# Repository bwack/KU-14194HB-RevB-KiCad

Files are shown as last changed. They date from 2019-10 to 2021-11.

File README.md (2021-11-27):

# KU-14194HB-RevB-KiCad

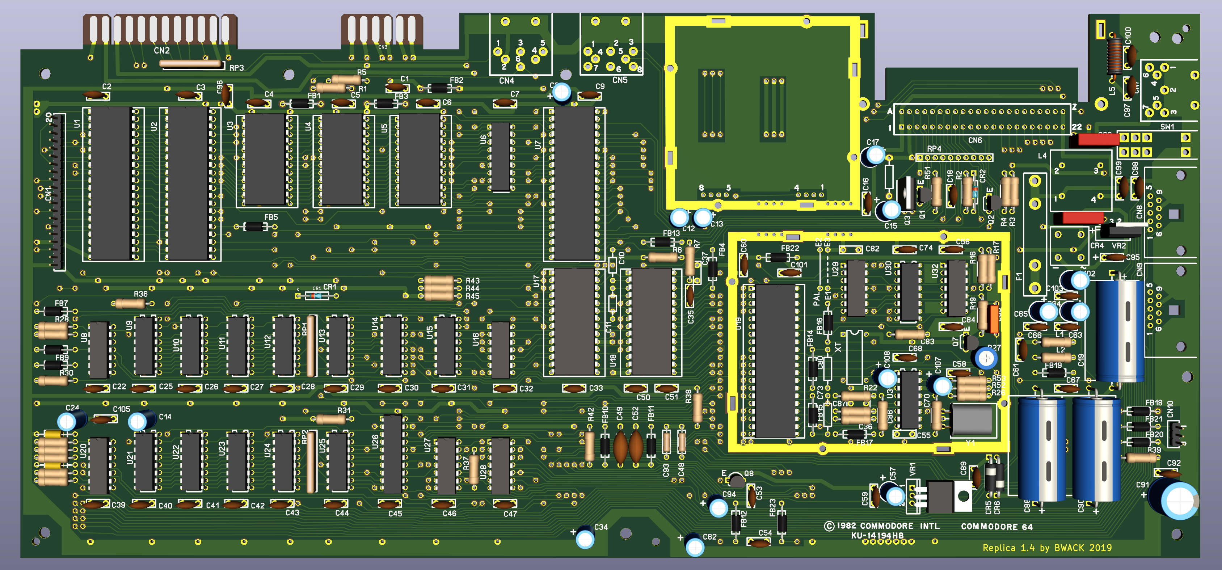
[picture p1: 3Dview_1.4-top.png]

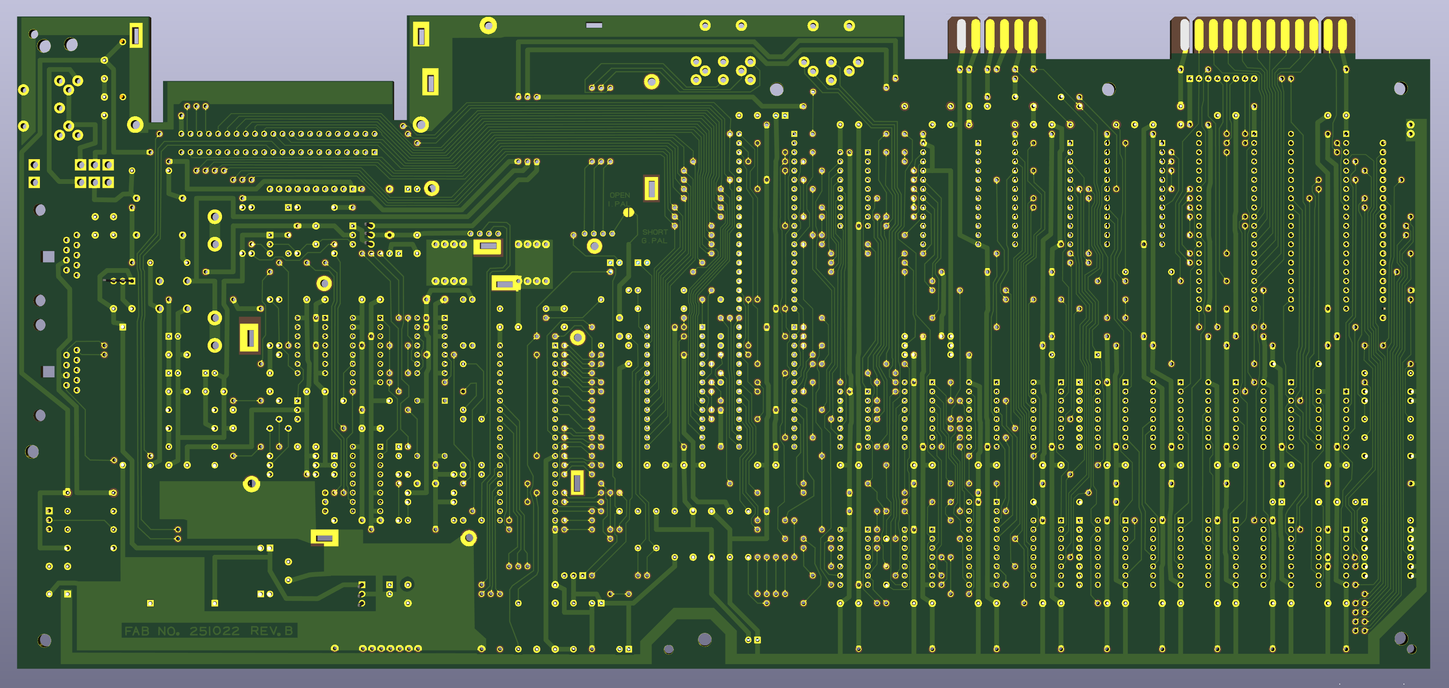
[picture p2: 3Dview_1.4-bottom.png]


The rare KU14194HB C64 Motherboard schematics and layout. Retraced in and imported from SprintLayout.

[Disclaimer](https://github.com/bwack/KU-14194HB-RevB-KiCad/blob/master/DISCLAIMER.md)

# Original bodges

This PCB is a replica. It includes the mistakes that Commodore made.

It is necessary to cut a trace above R37 on the bottom side, and add a 1K resistor from R37 and up to a via.
See the images folder to where to cut and add a resistor.

Piggyback a 100nF capacitor over CR1.

Notice how the main crystal oscillator Y1 body is grounded with a wire.

In later designs 250407 Reb B I think, 4 piggybacked diodes were introduced to protect the serial lines when hotplugging the disc drive.
I haven't added these myself, but I see the value of having those. I might add instructions here later on how to add the diodes.

# BOM

Please see the [BOM file](bom.csv).

# Interactive-BOM

[The interactive bom html page](https://htmlpreview.github.io/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) is useful for assembling the board and finding signal traces by using a web browser. Try it here. For a BOM for ordering parts see the BOM above.

# Questions

* Feel free post questions in the issues section. I will provide more information here later.

# Change log

- 2020-01-23: V1.4 PCB improvements:
  - Expansion Port: Larger round solder pads for the shield. Same error in the original.
  - Expansion Port: Connector moved to center of shield. Some traces moved.
  - Left edge: Extended the PCB by 2.2mm.
  - Left edge: Increased track width of the power rails.
  - CAN shield: added two solder pads.
  - RF modulator: added solder pad.
  - Schematics: Rev 1.4. No change.
- 2019-11-12: V1.3 Fixes: Mostly missing values.
  - C88: "1000uF 25V" -> "470uF 50uF". Commodore said 1000 but used 470.
  - R31: "180" -> "1K". A mistake in the commodore schematics.
  - R52: "?" -> "330"
  - R53: "?" -> "100"
  - C86: "?" -> "82pF",
  - C36: "0.1" -> "20pF",
  - R22: missing trace. R22 = 0 Ohm. Parallel to C87 (NC). R22 doesn't matter.
  - C101: is a Y5U. VIC2's decoupling cap. Has a higher dielectric rating. Doesn't matter.
  - C70: 15pF 5%. This is a PAL only board. In later revisions, 16pF is used for NTSC.
 - 2019-11-10 V1.2 Added missing C14 10uF 25V electrolytic capacitor
- 2019-10-15 V1.1 Layout: Fixed missing keying-slot in user port.
- 2019-10-05 V1.0 First release.

# YouTube

A playlist of all the videos:

[playlist](
https://www.youtube.com/watch?v=iNxOm7G6efA&list=PLtQOf_JULmrTGLZCElGG_T1a01JSDP0CP)

# In the wind

forum64.de: The board has some threads at forum64.de (German). May require login.
* [Bilder SHOWROOM für Repro-Boards... KU-14194HB](https://www.forum64.de/index.php?thread/97205-bilder-showroom-f%C3%BCr-repro-boards-ku-14194hb/&pageNo=1)
* [KU-14194 Bestückungs-Thread](https://www.forum64.de/index.php?thread/96336-ku-14194-best%C3%BCckungs-thread/)
* [KU-14194](https://www.forum64.de/index.php?thread/95454-ku-14194/) (long group buy thread)
* [KU-14194 (Replika) ... wer schafft es als Erste/r? Aktuelle Sachstandsberichte ...](https://www.forum64.de/index.php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)

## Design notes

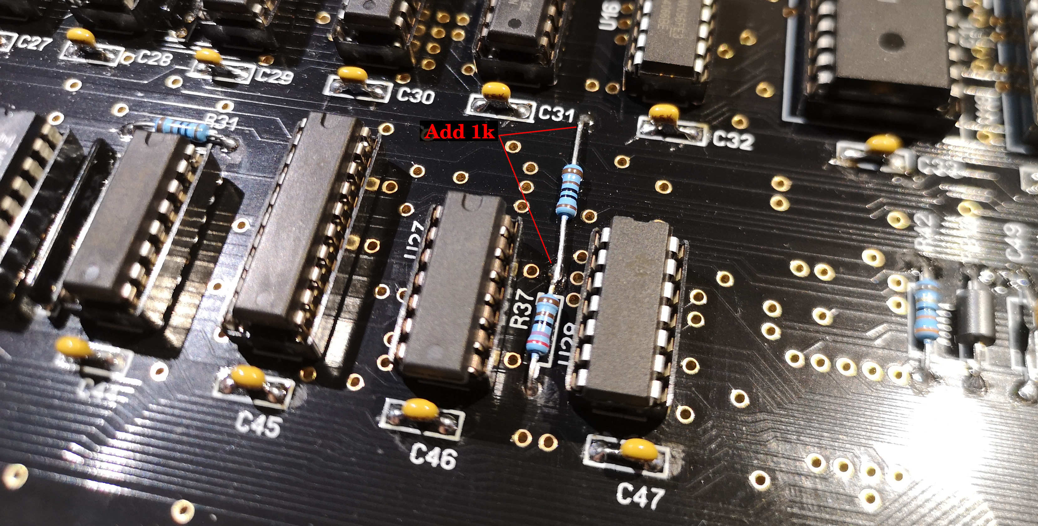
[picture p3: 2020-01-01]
images/r37_mod.jpg

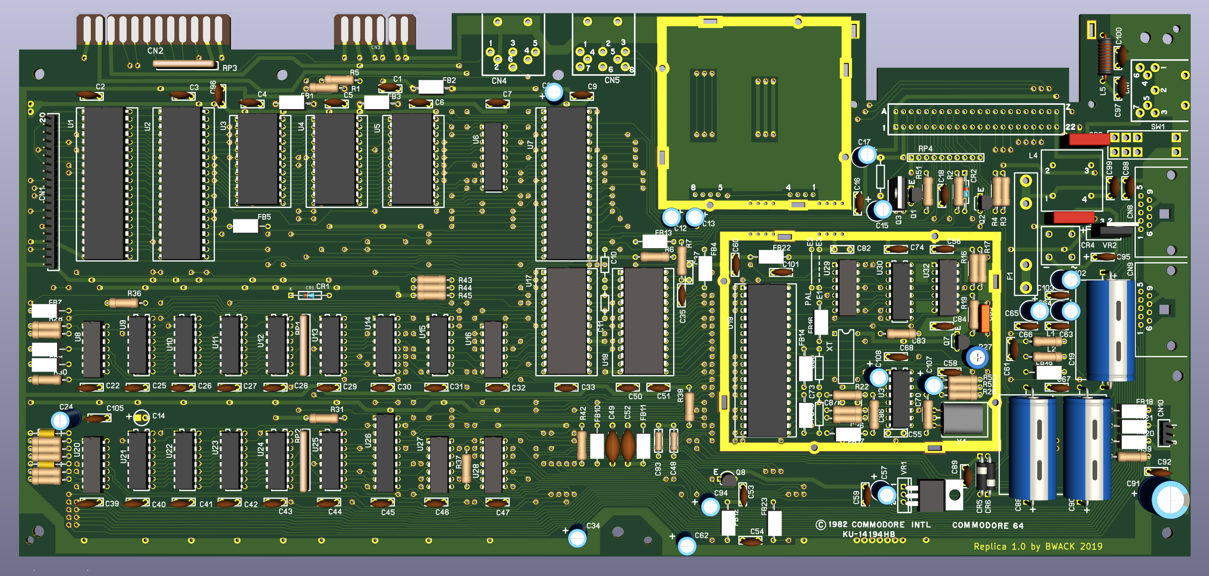
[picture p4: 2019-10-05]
3Dview_1.0_front.png

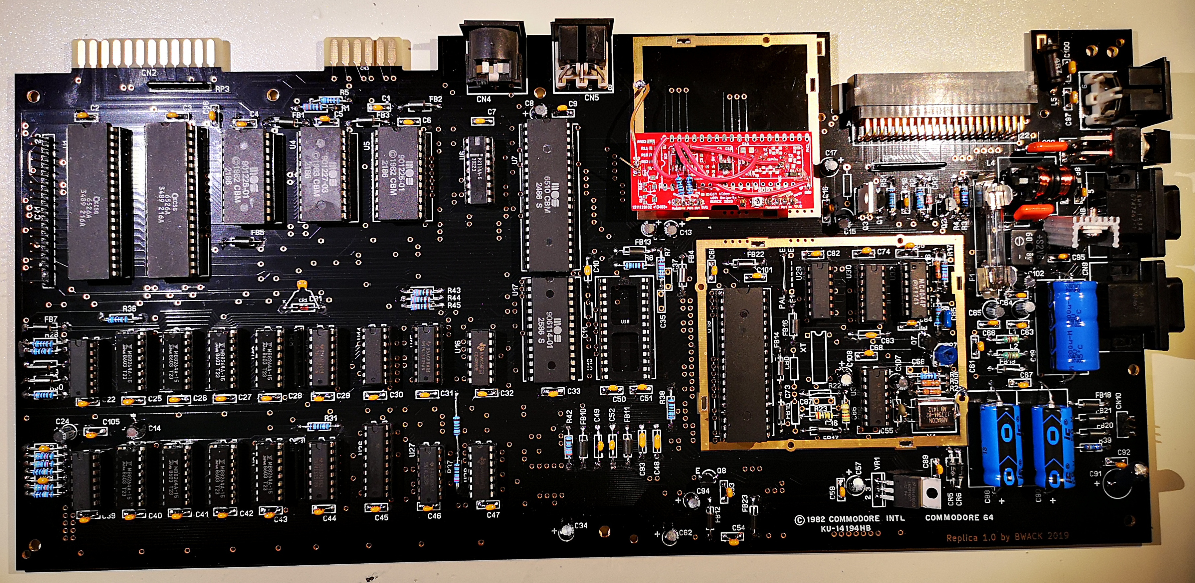
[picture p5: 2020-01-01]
images/IMG_20200101_211740_top_v1_0.jpg

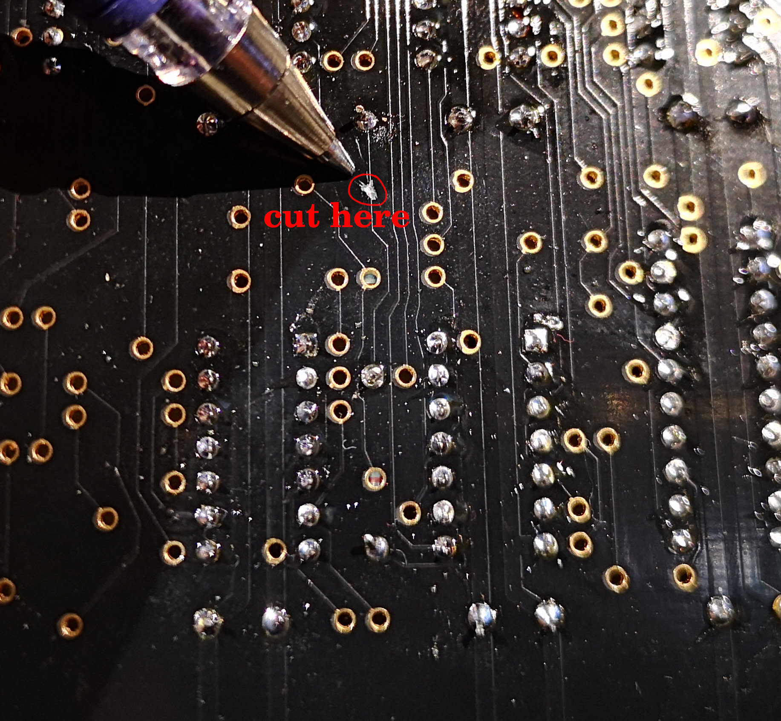
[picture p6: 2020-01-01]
images/r37_cut_trace.jpg

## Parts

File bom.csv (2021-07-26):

Qty | Reference(s) | Value | Description | Mouser P/N | Reichelt P/N | Other
56 | C1 C2 C3 C4 C5 C6 C7 C9 C16 C18 C22 C25 C26 C27 C28 C29 C30 C31 C32 C33 C39 C40 C41 C42 C43 C44 C45 C46 C47 C49 C50 C51 C52 C53 C54 C56 C58 C59 C60 C61 C63 C66 C67 C68 C74 C84 C89 C92 C95 C96 C98 C99 C101 C103 C105 and one piggybacked over CR1 | 0.1 | Cap MLCC 0.1uF 50V X7R P5.08mm Radial | 80-C322C104K5R5TA or 581-SR215C104KART | X7R-5 100N
16 | C8 C12 C13 C14 C15 C17 C24 C34 C57 C62 C64 C65 C94 C102 C107 C108 | 10uF | Cap Alu 10uF 25V 5x5mm P2.5mm Radial | 667-ECE-A1EKS100I | M 10U 25
2 | C10 C11 | 470pF | Cap MLCC 470pF X7R Axial | 594-A471K15X7RF5UAA | ?
1 | C19 | 2200uF | Cap Elyt 2200uF 16V 15x30mm Axial | 594-2222-021-16222 or 594-2222-021-15222 | COS 105 2200/16
2 | C20 C21 | 0.22 | Cap Polyester Film 0.22uF 63VAC P10mm | 594-2222-368-25224 | MKS4-100 220N2
1 | C23 | 350pF | Cap MLCC 350pF 50V C0G Axial | 594-A331J15C0GF5TAA | ?
4 | C35 C37 C55 C87 | NC | - | - | -
1 | C36 | 20pF | Cap MLCC 20pF C0G Axial | 581-SA102A200JAR | ?
1 | C38 | 51pF | Cap MLCC 51pF (47pF OK) X7R Axial | 581-SA102A470JAR | ?
2 | C48 C93 | 1800pF | Cap MLCC 1800pF X7R Axial | 581-SA101C182KAR | ?
1 | C70 | 15pF 5% | Cap MLCC 15pF 50V 5% C0G Axial/Radial Leaded | 594-A150J15C0GH5TAA | KERKO 15P
2 | C83 C86 | 82pF | Cap MLCC 82pF 100V C0G Axial / Radial Disc | 80-C410C820J1G
1 | C85 | 0.47 | Cap MLCC 0.47uF +80/-20% X7R P5.08mm Radial | 80-C330C474K5R | Z5U-5 470N
2 | C88 C90 | 470uF | Cap Elyt 470uF 50V 20% 13x26mm Axial | 598-477TTA050M | COS 105 470/50
1 | C91 | 100uF | Cap Elyt 100uF 16V 20% 6.3x11mm Radial | REA101M1CBK-0611P | FR-A 100U 16
2 | C97 C100 | 0.22 | Cap MLCC 0.22uF 50V X7R P5.08mm Radial | 80-C330C224K1R | Z5U-5 220N
1 | CN1 | KEYBOARD_20PIN_MALE | Pin Header 20 POS P2.54mm male vertical | 538-22-28-4204 | MPE 087-1-020
1 | CN4 | SERIAL_BUS_CON
1 | CN5 | AV_CONN
1 | CN6 | EXPANSION_PORT | Conn Edge Dual Female 44 POS P2.54mm |  |  | Digikey: H122591-ND
1 | CN7 | POWER_CON
2 | CN8 CN9 | CONTROL_PORT | Standard Connector DSUB E09P RA590 | 571-5747467-1
1 | CN10 | LED_CONNECTOR | Pin Header 3 POS P2.54mm male vertical | 538-22-28-4033 | RND 205-00624
1 | CR1 | IN4371 | Zener Diode 2.7V 500mW DO-35-2 | 78-TZX2V7A | ZF 2,7
1 | CR2 | IN755 | Zener Diode 7.5V 500mW DO-35-2 | 78-TZX7V5C | ZF 7,5
1 | CR4 | BRIDGE_RECTIFIER | Bridge Rectifier 2A 600V Vf=1.05V | 627-S2VB60-5000 | KBPC604 DIO
2 | CR5 CR6 | 1N4001 | Rectifier 1A Vr=50V | 625-1N4001-E3/54 or 625-1N4001-E3/53 | 1N 4001
1 | E1 | JUMPER_WIRE |  | - | - | -
2 | F1 | 1A | Fuse Clips (buy two) | 504-BK/1A1907-03-R | LITT 01020071Z
1 | FUSE | 1A | Fuse Glass 6x32mm 1A 250VAC slow | 530-3AG1-R | RND 170-00104
22 | FB4 FB10 FB11 FB12 FB13 FB14 FB15 FB18 FB22 FB1 FB2 FB3 FB5 FB7 FB8 FB9 FB16 FB17 FB19 FB20 FB2 FB23 | FERRITE_BEAD | Ferrite Bead 3.6x5mm Axial | 623-2743001112LF or 81-BL01RN1A2A2B | BEAD 8-21
2 | L1 L2 | 2.2uH | Inductor 2.2uH 5% Radial | 652-78F2R2J-RC | L-MICC 2,2µ
1 | L4 | CHOKE | Common Mode Choke 250V 3.8mH 2.1A 150mOhms | 80-SSR10V-21038
1 | L5 | 1.2uH | Inductor 1.5uH 10% Radial | 542-5800-4R7-RC | L-HBCC 1,5µ
1 | M1 | MODULATOR_LONGBOARD
4 | Q1 Q2 Q7 Q8 | 2SC1815 | Bipolar Transistor TO-92 Vce=60V 400mA | 2SC1815 | SC 1815
1 | Q3 | TP298/2SD880 | Bipolar Transistor TO-220 | 512-KSD880YTU | SD 880
4 | R1 R43 R44 R45 | 3K3 | Resistor 3K3 0207 Axial | 594-MBB02070C3301FC1 | METALL 3,30K
2 | R2 R51 | 1.5K | Resistor 1K5 0207 Axial | 594-MBB02070C1501FCT | 1W 1,5K
2 | R3 R7 | 10K | Resistor 10K 0207 Axial | 594-MBB02070C1002FCT | METALL 10,0K
10 | R4 R6 R16 R28 R29 R30 R31 R36 R38 and one bodge resistor (see images folder) | 1K | Resistor 1K 0207 Axial | 594-MBB02070C1001FCT | METALL 1,00K
1 | R5 | 560 | Resistor 560 0207 Axial | 594-MBB02070C5600FCT | METALL 560
2 | R17 R37 | 2K7 | Resistor 2K7 0207 Axial | 594-MBB02070C2701FCT | METALL 2,70K
1 | R19 | 15K | Resistor 15K 0207 Axial | 594-MBB02070C1502FC1 | METALL 15,0K
1 | R22 | 0R | Piece of resistor leg | - | -
1 | R23 | NC | - | - | -
2 | R26 R53 | 100 | Resistor 100 0207 Axial | 594-MBB02070C1000FCT | METALL 100
1 | R27 | 500 | Trimmer Resistor 500 Ohms Linear | 652-3306F-1-501 | BOU 3386P-1-501
2 | R33 R34 | 47K | Resistor 47K 0207 Axial | 594-MBB02070C4702FC1 | METALL 47,0K
1 | R35 | 470K | Resistor 470K 0207 Axial | 594-MBB02070C4703FCT | METALL 470K
1 | R39 | 390 | Resistor 390 0207 Axial | 594-MBB02070C3900FCT | METALL 390
2 | R41 R50 | 1M | Resistor 1M 0207 Axial | 594-MBB02070C1004FCT or 603-HHV-25JT-52-1M
1 | R42 | ~ | - | - | -
1 | R52 | 330 | Resistor 330 0207 Axial | 594-MBB02070C3300FCT
2 | RP1 RP2 | 33 | Resistor Network 33R Isolated 8 pin SIP | 652-4308R-2LF-33 or 268-33-RC
1 | RP3 | R_ARRAY_7WAY_US | Resistor Network 3K3 Bussed 8 pin SIP | 774-77081332P
1 | RP4 | R_ARRAY_9WAY_US | Resistor Network 3K3 Bussed 10 pin SIP | 774-770101332P
1 | SW1 | POWER_SWITCH
1 | U1 | CIA_U1
1 | U2 | CIA_U2
2 | U3 U4 | 2364A
1 | U5 | 2332A
1 | U6 | 2114
1 | U7 | 6510_MPU
1 | U8 | 7406N | Logic IC – Hex inverter | 595-SN74LS06N
8 | U9 U10 U11 U12 U21 U22 U23 U24 | 4164-2 | DRAM 1x64kb
1 | U13 U25 | 74LS257 |  | 595-SN74LS257BN
1 | U14 | 74LS258 |  | 595-SN74LS258BN
1 | U15 | 74LS139 |  | 595-SN74LS139AN
2 | U16 U28 | 4066_U28 |  | 595-CD4066BE
1 | U17 | PLA_U17
1 | U18 | 6581
1 | U19 | VIC
1 | U20 | 556 |  | 595-NE556NE4
1 | U26 | 74LS373 |  | 595-SN74LS373N
1 | U27 | 7408_U27 |  | 595-SN74LS08N
1 | U29 | 74LS74 |  | 595-SN74LS74AN
1 | U30 | 74LS193 |  | 595-SN74LS193N
1 | U31 | 74LS629N |  | 595-SN74LS629N
1 | U32 | MC4044
1 | VR1 | 7812 |  | 926-LM2940CT-12/NOPB
1 | VR2 | 7805 |  | 511-L4941BV
1 | XT1 | NOT USED
1 | Y1 | Crystal | Crystals 17.73447MHz 30ppm HC-49 18pF | 815-AB-17.734475-B4 | 17,7344-HC49U-S
C23 | 360 → 350

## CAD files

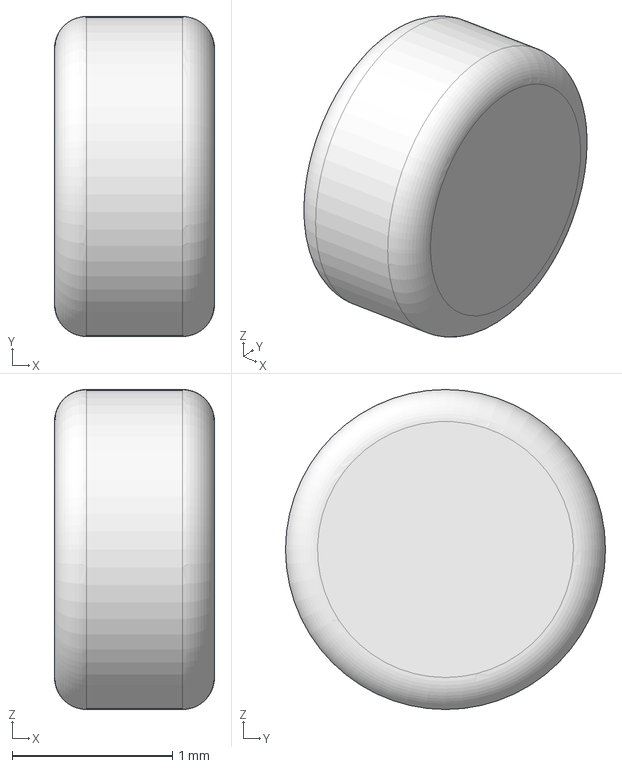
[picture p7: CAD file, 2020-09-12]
3D-models/unitary_ring.fcstd
1.00 x 2.00 x 2.00 mm

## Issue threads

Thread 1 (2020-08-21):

Edge connectors - 12 and 24 back paste issue

sjgray, 2020-08-21:
I tried using your 12 and 24 pin edge connector footprints in a project and I discovered a problem with the pins on the bottom of both parts. One pin on the bottom has a paste area and the others do not. this causes the pin to appear grey where all other pins are yellow on the 3D board view. Not sure if this affects the final board.

bwack, 2020-09-12:
Hi. Sorry for the long time to reply.
Many boards have been produced from this design, and the edge connectors are fine. I think you can see in the gerber files that the bottom solder mask layer is correct.. wait paste area ? You mean like SMD paste ? I'll have a double check..

bwack, 2020-09-12:
I see what you mean here. this layer is not used, but if it is a board you have smd components, and you are using a solderpaste stencil, then it is a problem.
PH
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

You can edit the footprint like here, remove the items in the paste layer, then save. Then go back to the design and update the footprint.
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

bwack, 2020-09-12:
I have changed to components now. removed solder paste. Moved solder mask from the pcb to the components. What remains is the edge cuts, those are not possible to move to the components, they have to drawn on the board.

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

bwack, 2020-09-12:
end result :-)

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

sjgray, 2020-09-14:
Looks good!
    On Saturday, September 12, 2020, 02:32:56 p.m. EDT, bwack <notifications@github.com> wrote:

end result :-)

—
You are receiving this because you authored the thread.
Reply to this email directly, view it on GitHub, or unsubscribe.

Closed 2020-10-28.

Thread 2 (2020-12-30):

Solder mask issue?

rljacobson, 2020-12-30:
Hi! Awesome project. You inspired me to do the 250469 Rev. B board.

I had five boards manufactured using your gerbers and noticed something unusual about the solder mask around the slots for the modulator and RF shield. The mask doesn't come up to the copper pour leaving bare FR4 surrounding the slot. Here's a picture:
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

It appears that it is this way in the design files.
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

In fact, according to the design files there *should* be an exposed bit around the border of the rest of the surrounding ground copper pour, and after a closer look I see them as well.

As far as I can tell it shouldn't affect anything, but maybe it would look nicer if the mask came all the way up to the copper.

Should the slots themselves be plated?

bwack, 2021-01-02:
Hi! Thanks for the feedback. It is very cool that you are doing the same with the 250469! Recently I've taken over a sprintlayout project file of the 250407 and I'm continuing the work on it :)
Hi you are right, the solder mask does not come up to all the pads. It is then a question if I should change it, but since it is a replica I'll keep it this way.

The original board does not have plated through slots. When I produced the boards, the producer asked if I wanted plated slots, and I answered yes. I don't know if it is posible to specify this in the KiCad software.

Hans

rljacobson, 2021-01-04:
I agree that you should keep it if the original has the same feature.

> I don't know if it is possible to specify this in the KiCad software.

I don't believe so, except of course for a written comment on User.Comments.

I can't wait to see your 250407! Here is a preview of my 250469 Rev. B:

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

The original board has a bunch of these geometric copper zones: 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

It is hard to deal with them, and they are not all just GND/PWR fills on either side. Worse, my reference pictures clearly show they are not computer drawn, as some have rounded over corners, irregularly angled lines, fills not filling the available space, etc. What's weird is that Rev. A *does* look like it was computer drawn, very neat and regular. So they relaxed a bit for Rev B.? Strange. Anyway, I don't see these on your KU board, I guess because of the density of the traces. But I can tell that the traces and these fills will make it a DRC nightmare.

bwack, 2021-01-06:
Great work on the 250469.
Have you seen this ? http://www.c-64.org/de/mainboards.html unfortunately it does not have images of the pcb bottom side.
DRC is indeed very exhaustive :)

rljacobson, 2021-01-07:
Yep, I have a lot of good reference photos. I need them especially because I don't own a C64 motherboard. It is mysterious to me how features in different photos can be so misaligned when they are identical in reality.

Closed 2021-01-07.

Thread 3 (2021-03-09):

Someone changed the silkscreen and claimed your PCB as their own

xiphias256, 2021-03-09:
It came to my discovery on a Facebook group that someone took your PCB design, just changed the silkscreen and claiming it to be their own. Just want you to know what happened, if you where unaware.

https://retrotechlyfe.com/home/ols/products/commodore-64-8-bit-computer-motherboard-logic-board-premium-gold-immersed-traces-stellar-signal-integrity

Keep up the good work!!

xiphias256, 2021-03-10:
After writing an email to the person responsible, he now at least give you credit. But no link to this github project.

bwack, 2021-03-10:
Thanks!

Closed 2021-03-10.

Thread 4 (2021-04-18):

No video

fab1979, 2021-04-18:
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
Tried everything i could think of voltages look fine checked mos chips on a working machine. Im new to soldering and pcboards, i had a friend (electrical engineer) to see if he could figure out anything with no luck. Any info on what i could try would be very appreciated.

Langwell, 2021-04-20:
Try a 330ohm resistor at R42

fab1979, 2021-04-20:
You sir are the man Thank You
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

fab1979, 2021-04-20:
Only issue is its not a steady image it flickers a little but it works.

Langwell, 2021-04-21:
> Only issue is its not a steady image it flickers a little but it works.

> You sir are the man Thank You
> 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

Great to see you up and running, check on another TV, I've seen perfectly working C64 machines display perfectly on one TV and experience things like sudden brightness changes on others.  There is a helpful KU-14194 assembly thread on Forum64.de

Closed 2021-07-26.

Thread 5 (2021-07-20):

File not checked into repo

weerligbytjie, 2021-07-20:
I tried to open the schematic and it is complaining that KU-14194HB-REV-B-KiCad-rescue.lib not being found.
Kicad then hangs.

bwack, 2021-07-26:
Thanks! I've added and pushed the file to the repo.

weerligbytjie, 2021-07-26:
Still asking for KU-14194HB-REV-B-KiCad-rescue.lib

bwack, 2021-07-26:
$ git add KU-14194HB-REV-B-KiCad-rescue.lib
The following paths are ignored by one of your .gitignore files:
KU-14194HB-REV-B-KiCad-rescue.lib
Use -f if you really want to add them.

Ahh. my bad. Thanks for your patience :smile:

Closed 2021-11-27.

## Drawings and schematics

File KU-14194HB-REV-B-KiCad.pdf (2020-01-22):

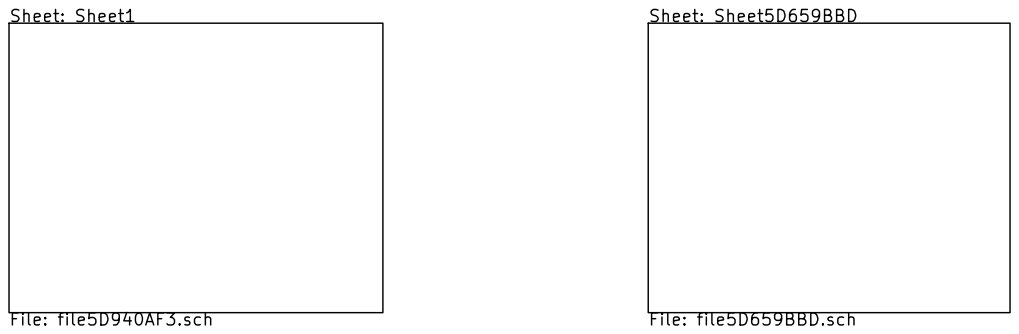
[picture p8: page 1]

layout retraced and schematics drawn by bwack 2019
File: KU-14194HB-REV-B-KiCad.sch Sheet: / Commodore 1982

Id: 1/3 Title: C64 Motherboard KU-14194HB

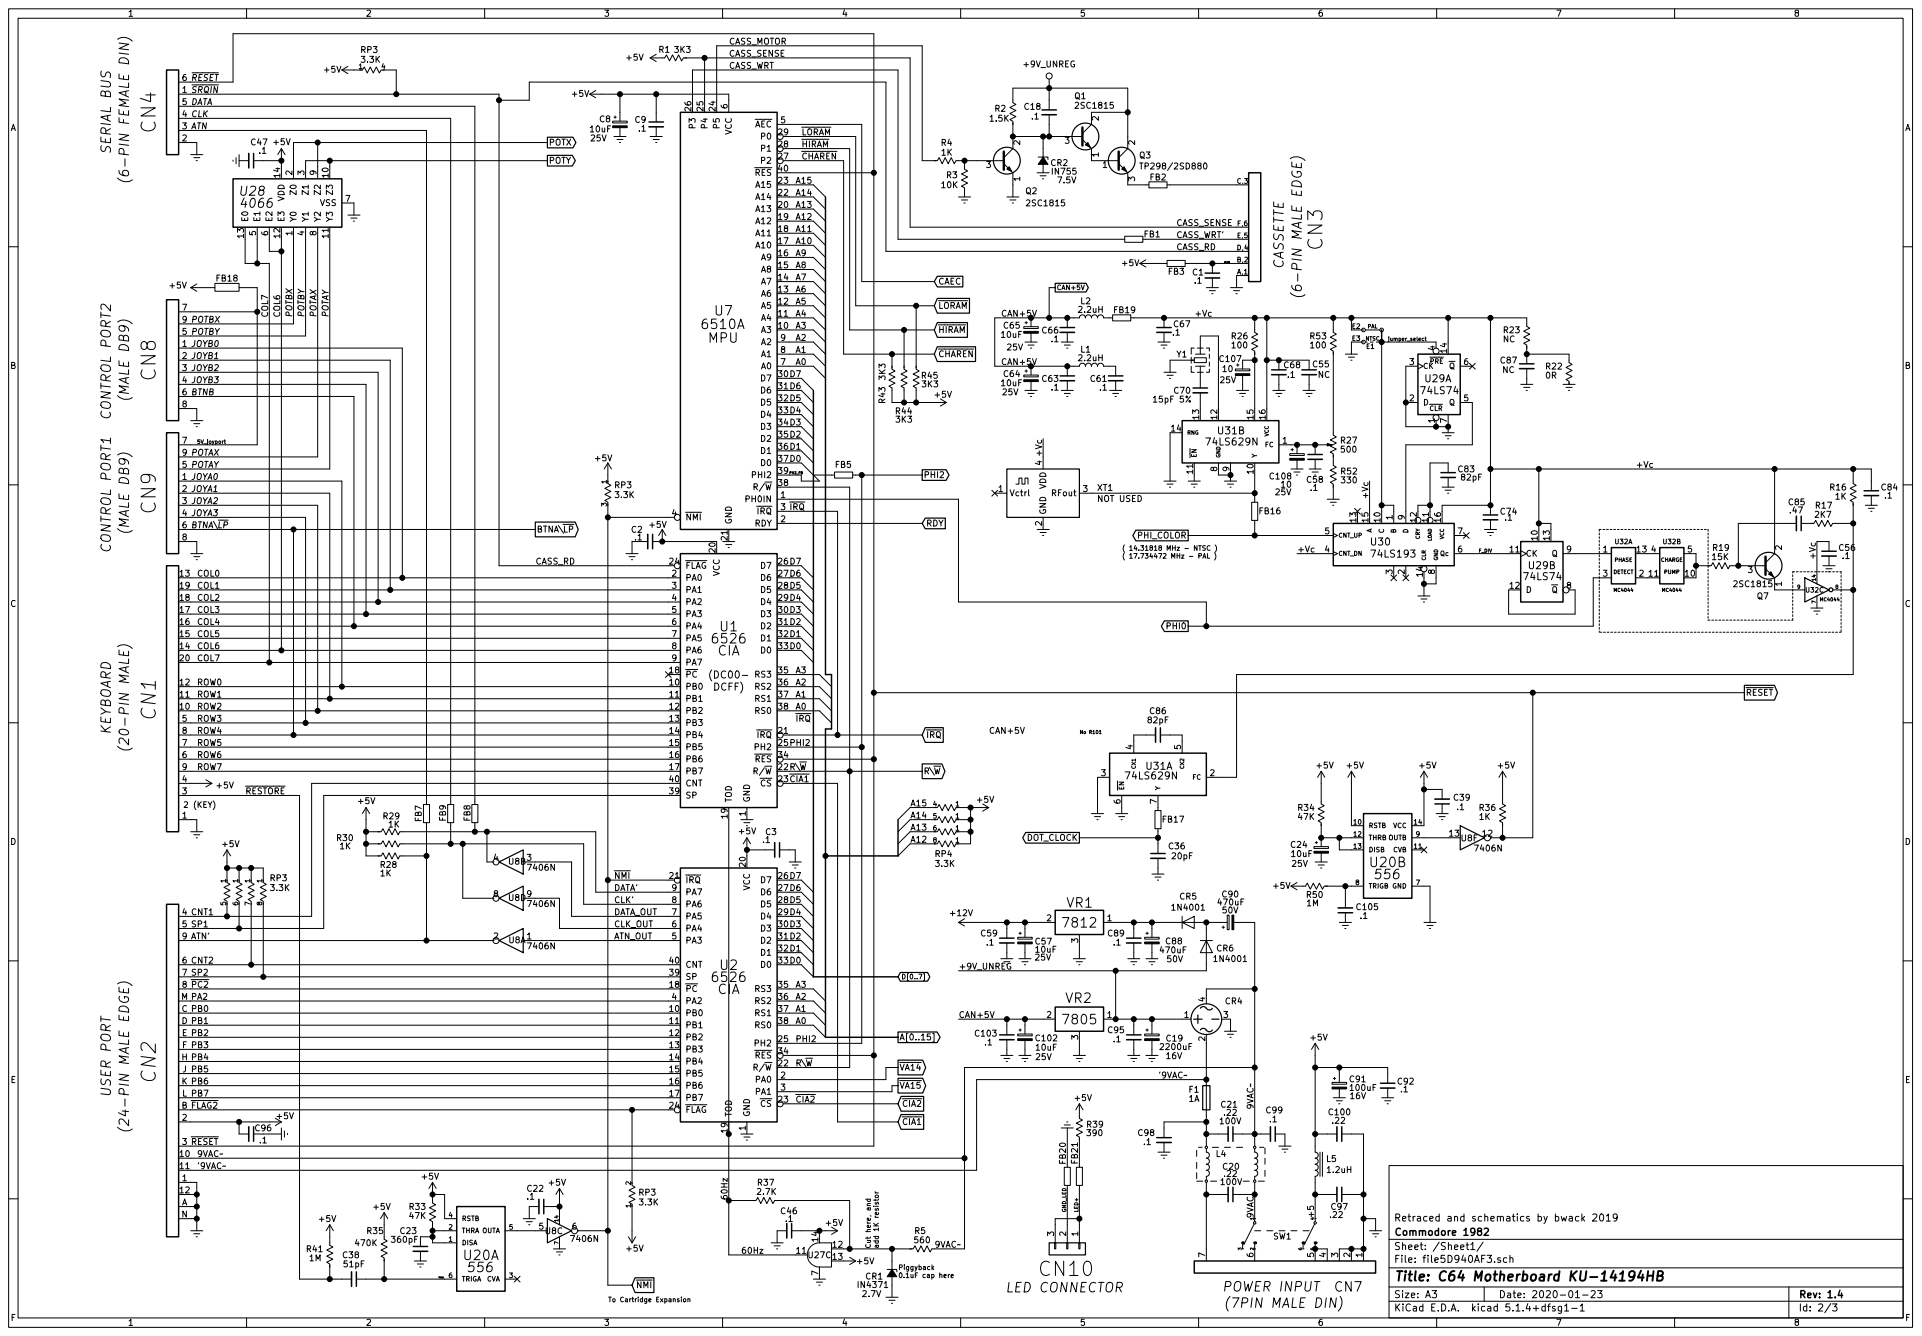
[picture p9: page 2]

D5A1 USER PORT CONTROL PORT2 (MALE DB9) (6-PIN FEMALE DIN) (24-PIN MALE EDGE) SERIAL BUS

JOYB3 POTBY 1 JOYB0

PAL

25V Cut here, and add 1K resistor (20-PIN MALE)

2 JOYB1

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
5 | CIA1 IRQ

ROW2 8

7 | 1K R35 | PHI2 ATN'

9A D PB1

PA2 PB0
BC FH PB3
PB4 PB5 PB6 PB7 FLAG2 RESET

CIA GND

10 9VAC
11 '9VAC

Id: 2/3 Title: C64 Motherboard KU-14194HB

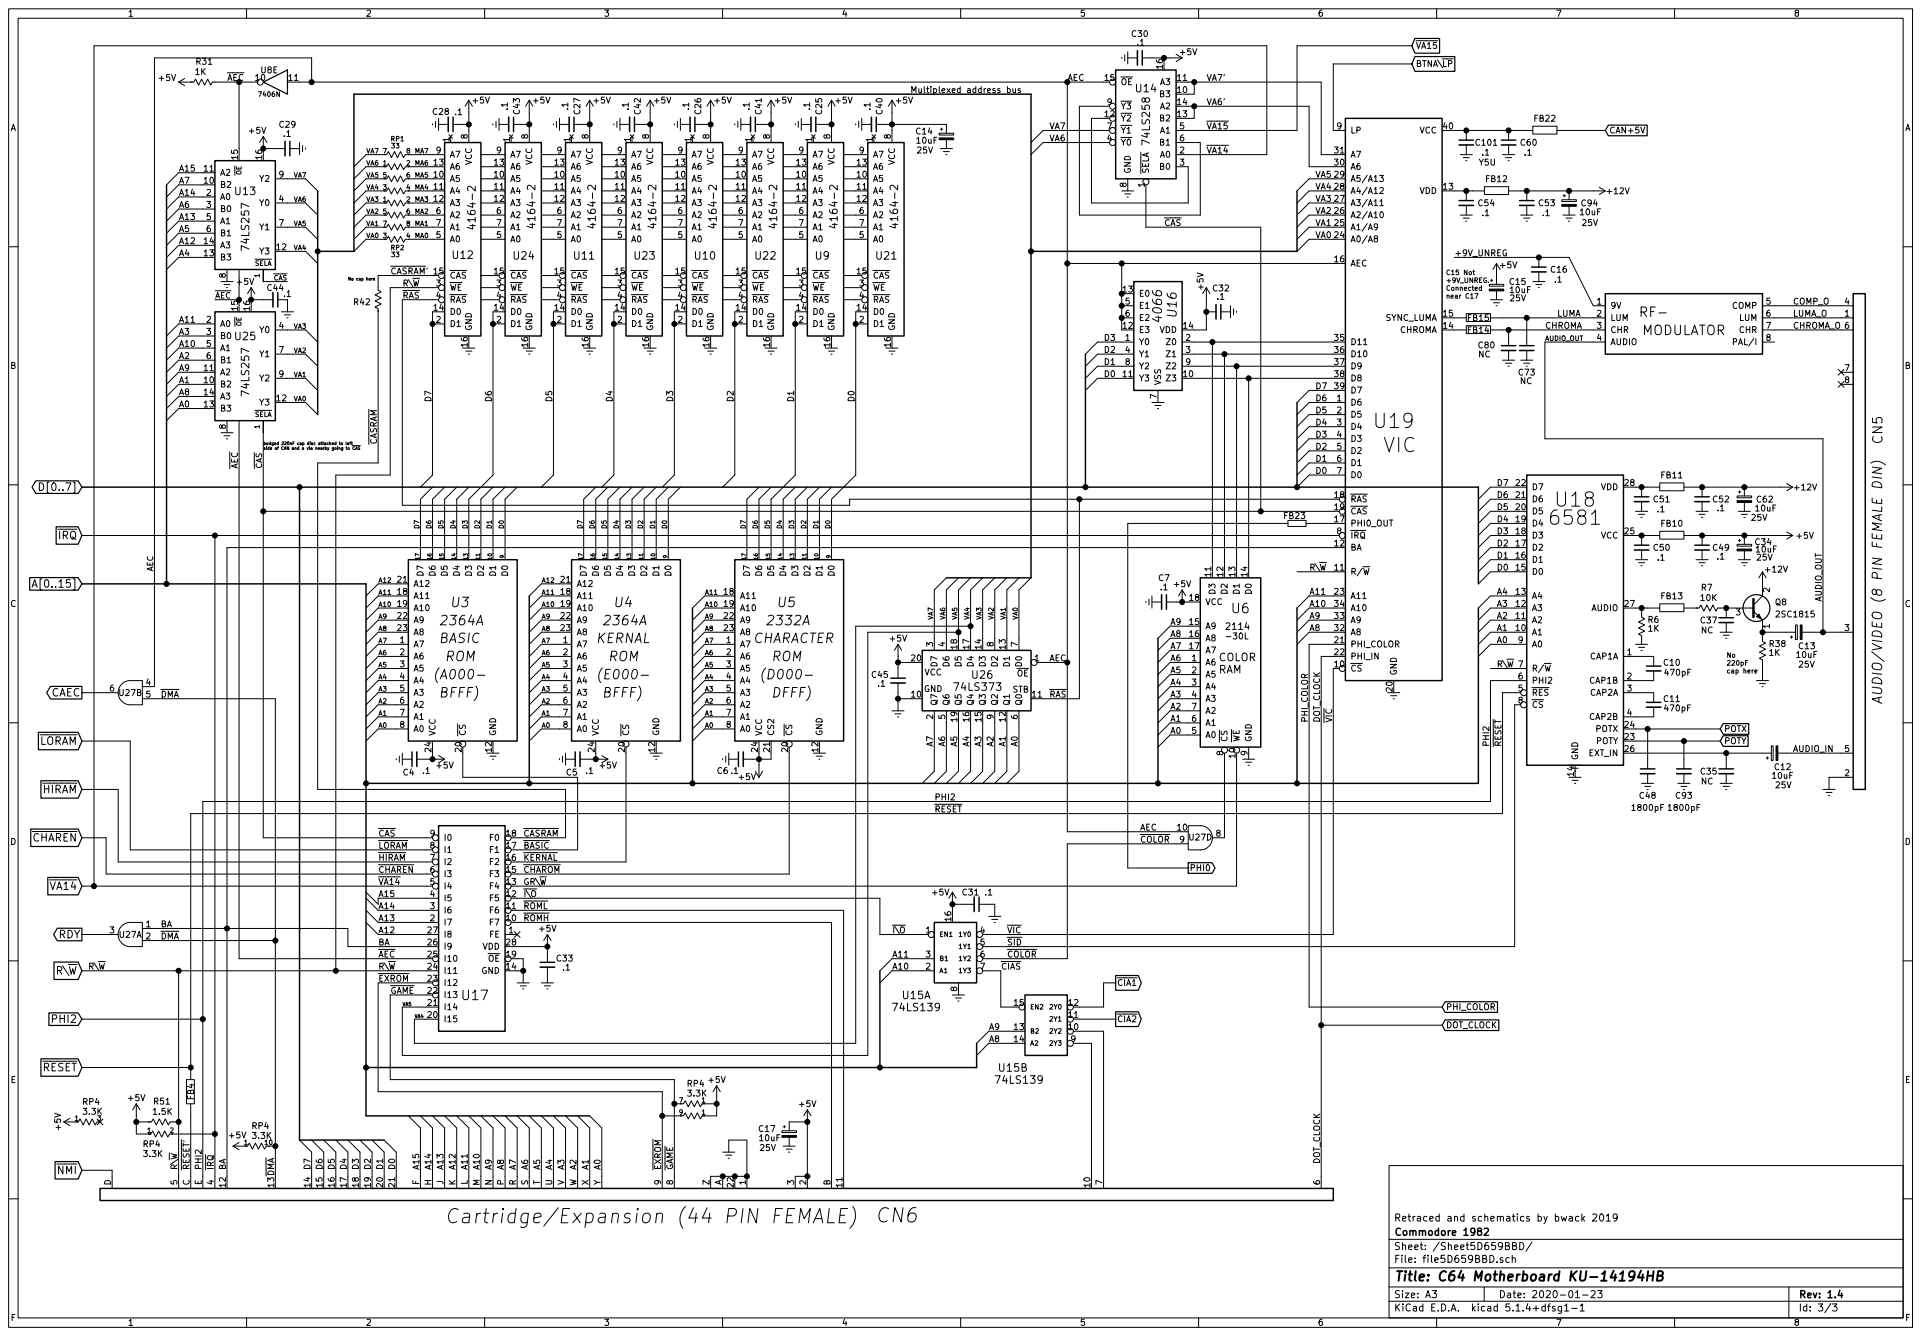
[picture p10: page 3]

1 A5 10 A4 11 A3 12 A6 13 D0 14 CAS 15 GND 16 D1 2 WE 3 RAS 4 A0 5 A2 6 A1 7 VCC

Cartridge/Expansion (44 PIN FEMALE)

File: file5D659BBD.sch Sheet: /Sheet5D659BBD/ Commodore 1982 Retraced and schematics by bwack 2019

Id: 3/3 Title: C64 Motherboard KU-14194HB

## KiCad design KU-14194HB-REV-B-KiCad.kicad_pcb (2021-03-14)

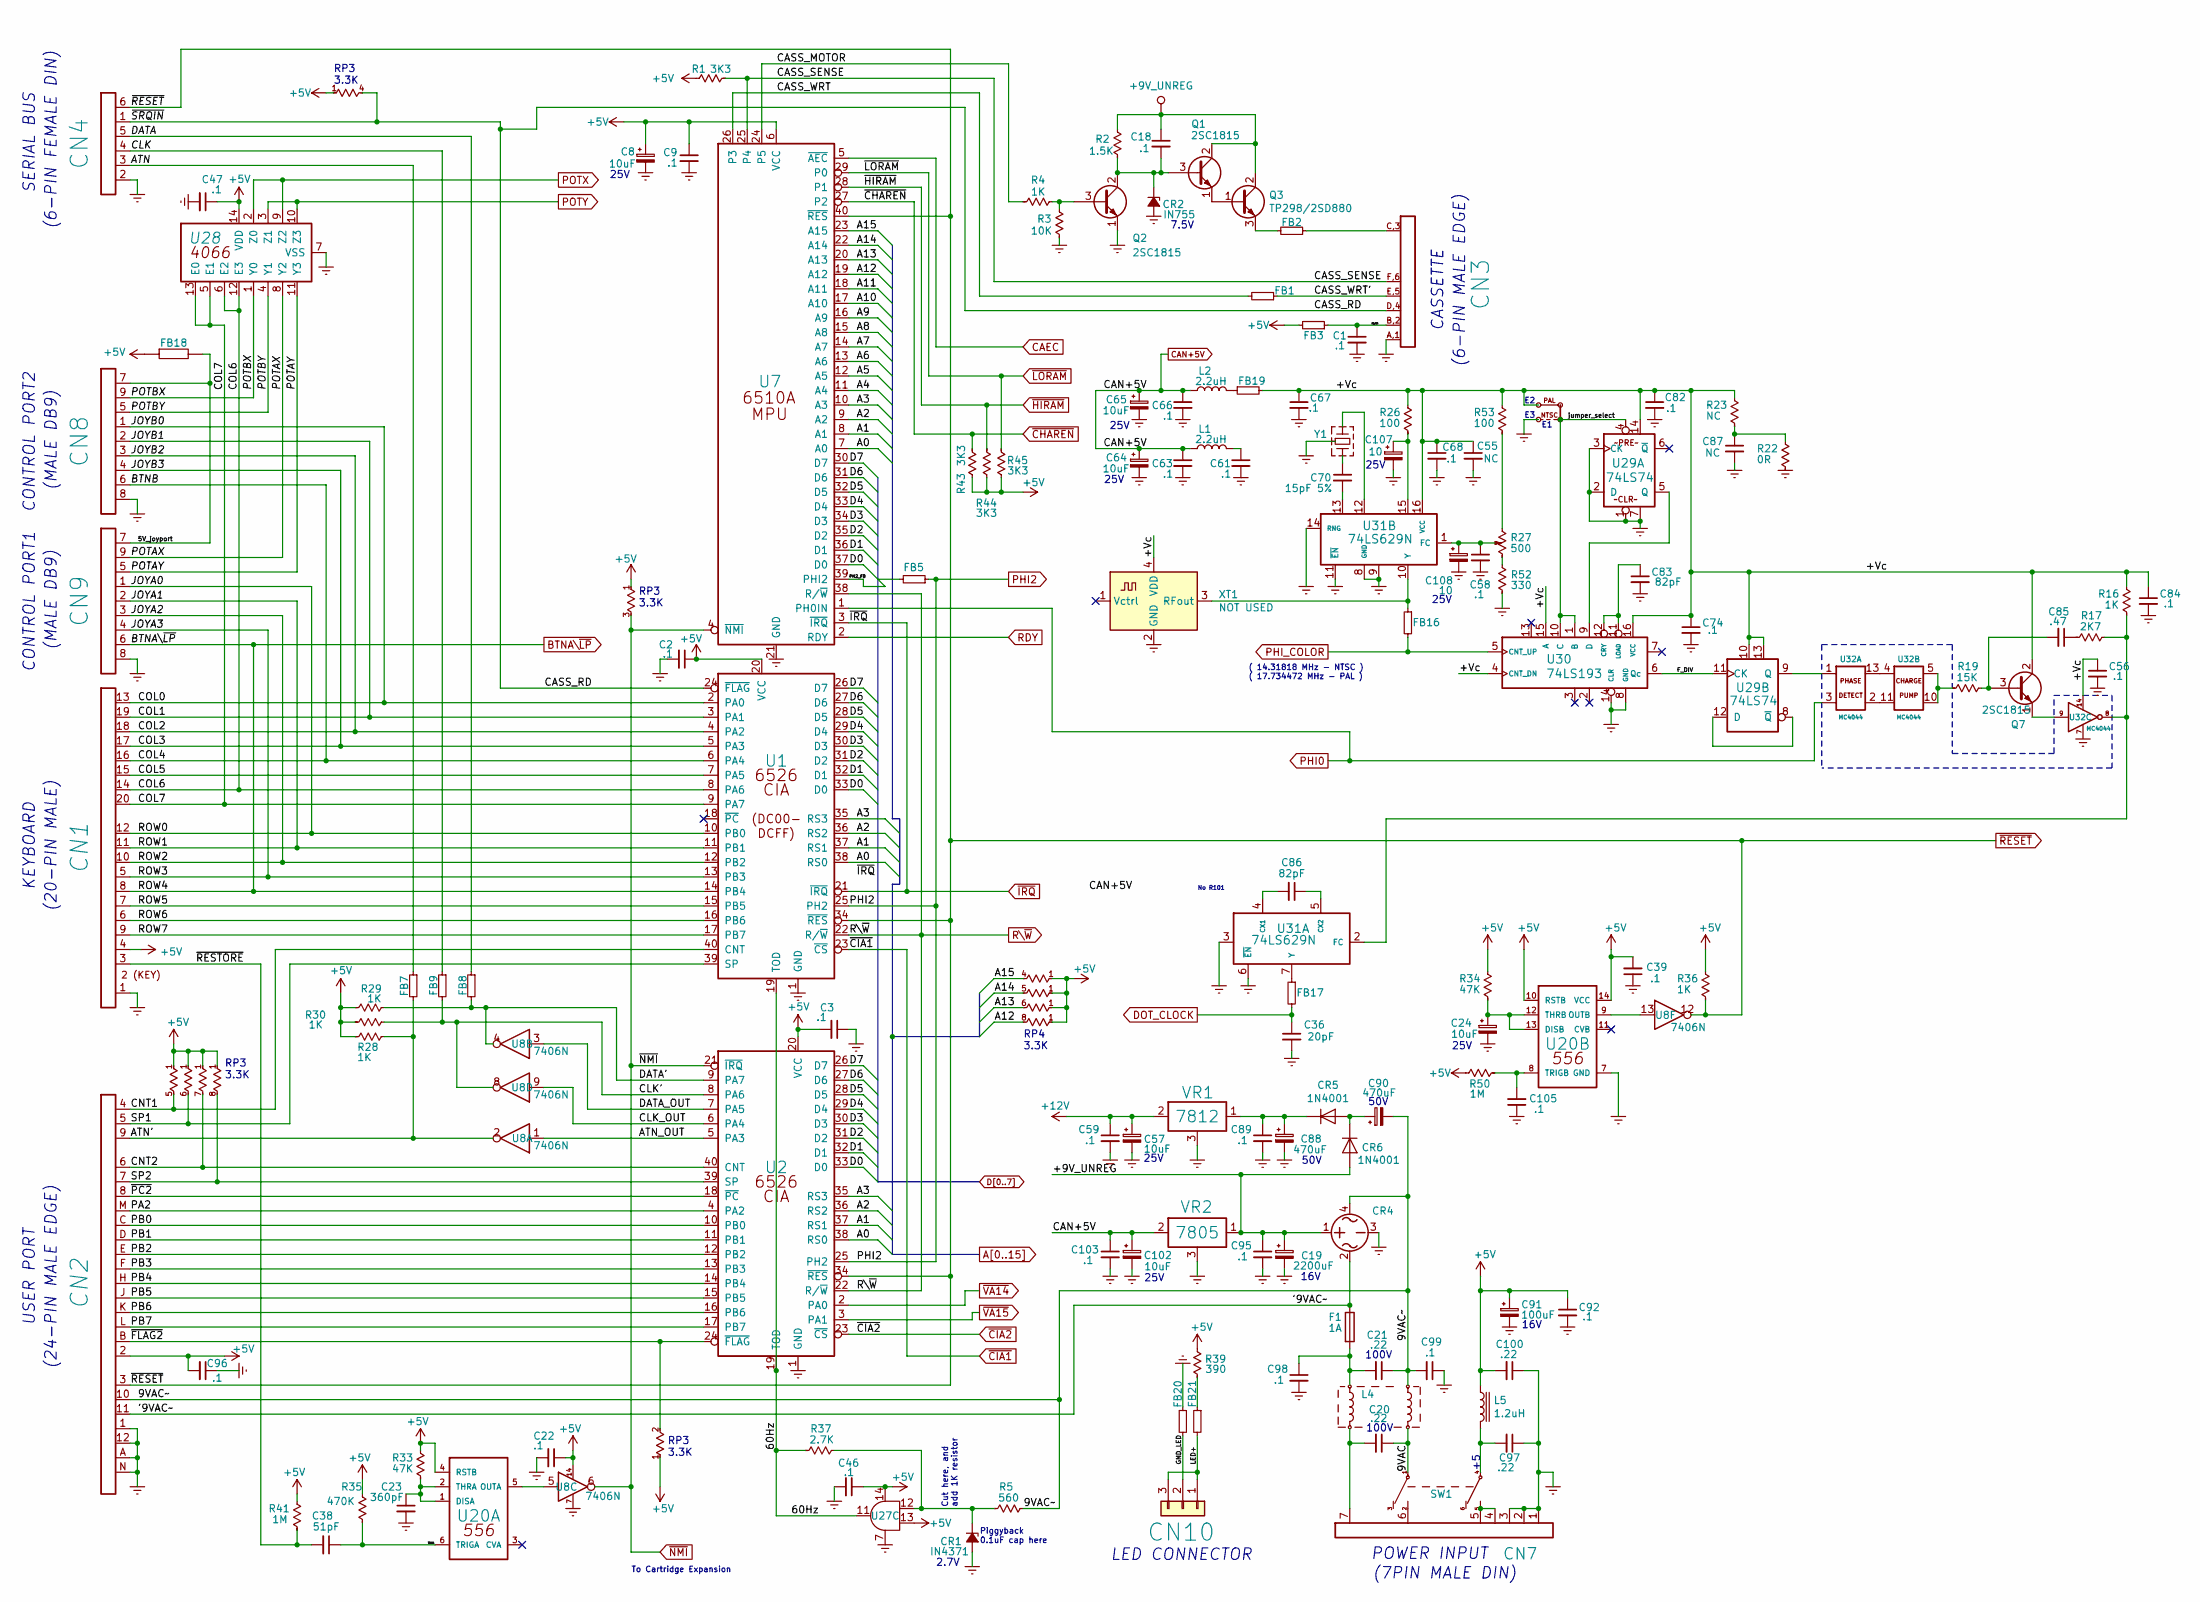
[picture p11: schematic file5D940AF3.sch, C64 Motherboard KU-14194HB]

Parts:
C1, C2, C3, C9, C18, C22, C39, C46, C47, C56, C58, C59, C61, C63, C66, C67, C68, C74, C82, C84, C89, C92, C95, C96, C98, C99, C103, C105: .1; CAP_P5.08mm
C8, C24, C57, C64, C65, C102: 10uF; CAP_ELYT_RADIAL_P2.54mm
C19: 2200uF; LARGE_ELECTROLYTIC_33x18_P38.10mm_AXIAL_TH
C20, C21: .22; CAP_POLY_100V_TH_P10.16mm
C23: 360pF; CAP_AXIAL_P12.7mm
C36: 20pF; RESISTOR
C38: 51pF; CAP_AXIAL_P12.7mm
C55, C87: NC; CAP_P5.08mm
C70: 15pF 5%; RESISTOR
C83, C86: 82pF; RESISTOR
C85: .47; CAP_P5.08mm
C88, C90: 470uF; LARGE_ELECTROLYTIC_33x18_P38.10mm_AXIAL_TH
C91: 100uF; CAP_ELYT_RADIAL_P5.08mm
C97, C100: .22; CAP_P5.08mm
C107, C108: 10; CAP_ELYT_RADIAL_P2.54mm
CN1: KEYBOARD_20PIN_MALE; KEYBOARD_CON
CN2: USER_PORT_CON; EDGE_CON_24P
CN3: CASSETTE_PORT_CON; EDGE_CON_12P_TAPE
CN4: SERIAL_BUS_CON; SERIAL_CON_DIN6
CN7: POWER_CON; POWER_CON_DIN7
CN8, CN9: CONTROL_PORT; JOYPORT_DB9
CN10: LED_CONNECTOR; LED_CON
CR1: IN4371; ZENER_12.7mm
CR2: IN755; ZENER_12.7mm
CR4: BRIDGE_RECTIFIER
CR5, CR6: 1N4001; RECTIFIER_TH_P12.7mm
E1: JUMPER_WIRE
F1: 1A; FUSE
FB1, FB2, FB3, FB5, FB7, FB8, FB9, FB16, FB17, FB19, FB20, FB21: FERRITE_NARROW; FERRITE_BEAD_TH_P12.7mm
FB18: FERRITE_BEAD; FERRITE_BEAD_TH_P12.7mm
L1, L2: 2.2uH; RESISTOR
L4: CHOKE
L5: 1.2uH; INDUCTOR_P15.24mm
Q1, Q2, Q7: 2SC1815; Q_NPN_ECB
Q3: TP298/2SD880; TO-220-3_Vertical
R1, R43, R44, R45: 3K3; RESISTOR
R2: 1.5K; RESISTOR
R3: 10K; RESISTOR
R4, R16, R28, R29, R30, R36: 1K; RESISTOR
R5: 560; RESISTOR
R17: 2K7; RESISTOR
R19: 15K; RESISTOR
R22: 0R; RESISTOR
R23: NC; RESISTOR
R26, R53: 100; RESISTOR
R27: 500; POTMETER
R33, R34: 47K; RESISTOR
R35: 470K; RESISTOR
R37: 2.7K; RESISTOR
R39: 390; RESISTOR
R41, R50: 1M; RESISTOR
R52: 330; RESISTOR
RP3: R_ARRAY_7WAY_US; RP_ARRAY_7WAY
RP4: R_ARRAY_9WAY_US; RP_ARRAY_9WAY
SW1: POWER_SWITCH
U1: CIA_U1; DIP40
U2: CIA_U2; DIP40
U7: 6510_MPU; DIP40
U8: 7406N; DIP14
U20: 556; DIP14
U27: 7408_U27; DIP14
U28: 4066_U28; DIP14
U29: 74LS74; DIP14
U30: 74LS193; DIP16
U31: 74LS629N; DIP16
U32: MC4044; DIP14
VR1: 7812; VOTLAGE_REGULATOR_TO220
VR2: 7805; VOTLAGE_REGULATOR_TO220
XT1: NOT USED; DIP4_DIP14_but_4_pins
Y1: Crystal; CRYSTAL

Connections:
+5V: C2.1, C3.2, C8.1, C9.1, C22.1, C39.2, C46.1, C47.1, C91.1, C92.1, C96.2, C100.2, CN1.4, CN2.2, FB3.2, FB18.1, L5.1, R1.1, R28.2, R29.2, R30.2, R33.1, R34.1, R35.1, R36.1, R39.1, R41.1, R43.1, R44.1, R45.1, R50.1, RP3.1, RP4.1, U1.20 (VCC), U2.20 (VCC), U7.6 (VCC), U8.14, U20.4 (RSTB), U20.10 (RSTB), U20.14 (VCC), U27.13, U27.14, U28.14 (VDD); also elsewhere on the board
+9V_UNREG: C18.1, C19.1, C95.1, CR4.1, CR6.2 (A), Q1.2 (C), Q3.2 (C), R2.1, VR2.1; also elsewhere on the board
+12V: C57.1, C59.1, VR1.2; also elsewhere on the board
/Sheet1/5V_FB3: C1.1, CN3.B,2, FB3.1
/Sheet1/5V_joyport: CN8.7, CN9.7, FB18.2
/Sheet1/9VAC: C20.1, L4.3, SW1.1
/Sheet1/9VAC~~: C21.1, C90.2, C99.2, CN2.10, CR4.4, L4.4, R5.1
/Sheet1/60Hz: R37.2, U1.19 (TOD), U2.19 (TOD), U27.11
/Sheet1/'9VAC~~: CN2.11, CR4.2, F1.1
/Sheet1/+Vc: C55.1, C56.1, C67.1, C68.1, C74.1, C82.1, C84.1, E1.1, FB19.2, Q7.2 (C), R16.1, R23.1, R26.1, R53.1, U29.10, U29.13, U29.14, U30.4 (CNT_DN), U30.15 (A), U30.16 (VCC), U31.16 (VCC), U32.14, XT1.4 (VDD)
/Sheet1/ATN: CN4.3, FB7.1
/Sheet1/ATN': CN2.9, FB7.2, R28.1, U8.2
/Sheet1/ATN_OUT: U2.5 (PA3), U8.1
/Sheet1/BTNB: CN1.16, CN8.6, U1.6 (PA4)
/Sheet1/CASS_MOTOR: R4.2, U7.24 (P5)
/Sheet1/CASS_RD: CN3.D,4, CN4.1, RP3.4, U1.24 (~FLAG~)
/Sheet1/CASS_SENSE: CN3.F,6, R1.2, U7.25 (P4)
/Sheet1/CASS_WRT: FB1.2, U7.26 (P3)
/Sheet1/CASS_WRT': CN3.E,5, FB1.1
/Sheet1/CLK: CN4.4, FB9.1
/Sheet1/CLK': FB9.2, R30.1, U2.8 (PA6), U8.8
/Sheet1/CLK_OUT: U2.6 (PA4), U8.9
/Sheet1/CNT1: CN2.4, RP3.5, U1.40 (CNT)
/Sheet1/CNT2: CN2.6, RP3.7, U2.40 (CNT)
/Sheet1/COL0: CN1.13, CN8.1, U1.2 (PA0)
/Sheet1/COL1: CN1.19, CN8.2, U1.3 (PA1)
/Sheet1/COL2: CN1.18, CN8.3, U1.4 (PA2)
/Sheet1/COL3: CN1.17, CN8.4, U1.5 (PA3)
/Sheet1/COL5: CN1.15, U1.7 (PA5)
/Sheet1/COL6: CN1.14, U1.8 (PA6), U28.6 (E2), U28.12 (E3)
/Sheet1/COL7: CN1.20, U1.9 (PA7), U28.5 (E1), U28.13 (E0)
/Sheet1/DATA: CN4.5, FB8.1
/Sheet1/DATA': FB8.2, R29.1, U2.9 (PA7), U8.4
/Sheet1/DATA_OUT: U2.7 (PA5), U8.3
/Sheet1/F_DIV: U29.11 (CK), U30.6 (Qc)
/Sheet1/GND_LED: CN10.2, FB20.2
/Sheet1/JOYA0: CN1.12, CN9.1, U1.10 (PB0)
/Sheet1/JOYA1: CN1.11, CN9.2, U1.11 (PB1)
/Sheet1/JOYA2: CN1.10, CN9.3, U1.12 (PB2)
/Sheet1/JOYA3: CN1.5, CN9.4, U1.13 (PB3)
/Sheet1/LED+: CN10.1, CN10.3, FB21.2
/Sheet1/PA2: CN2.M, U2.4 (PA2)
/Sheet1/PB0: CN2.C, U2.10 (PB0)
/Sheet1/PB1: CN2.D, U2.11 (PB1)
/Sheet1/PB2: CN2.E, U2.12 (PB2)
/Sheet1/PB3: CN2.F, U2.13 (PB3)
/Sheet1/PB4: CN2.H, U2.14 (PB4)
/Sheet1/PB5: CN2.J, U2.15 (PB5)
/Sheet1/PB6: CN2.K, U2.16 (PB6)
/Sheet1/PB7: CN2.L, U2.17 (PB7)
/Sheet1/PH2_FB: FB5.2, U7.39 (PHI2)
/Sheet1/POTAX: CN9.9, U28.8 (Y2)
/Sheet1/POTAY: CN9.5, U28.11 (Y3)
/Sheet1/POTBX: CN8.9, U28.1 (Y0)
/Sheet1/POTBY: CN8.5, U28.4 (Y1)
/Sheet1/ROW5: CN1.7, U1.15 (PB5)
/Sheet1/ROW6: CN1.6, U1.16 (PB6)
/Sheet1/ROW7: CN1.9, U1.17 (PB7)
/Sheet1/SP1: CN2.5, RP3.6, U1.39 (SP)
/Sheet1/SP2: CN2.7, RP3.8, U2.39 (SP)
/Sheet1/TRIGA: C38.1, R35.2, U20.6 (TRIGA)
/Sheet1/jumper_select: E1.C, U29.4, U30.1 (B), U30.10 (C)
/Sheet1/~FLAG2~: CN2.B, RP3.2, U2.24 (~FLAG~)
/Sheet1/~PC2~: CN2.8, U2.18 (~PC~)
/Sheet1/~RESTORE~: C38.2, CN1.3, R41.2
A0: U1.38 (RS0), U2.38 (RS0), U7.7 (A0); also elsewhere on the board
A1: U1.37 (RS1), U2.37 (RS1), U7.8 (A1); also elsewhere on the board
A2: U1.36 (RS2), U2.36 (RS2), U7.9 (A2); also elsewhere on the board
A3: U1.35 (RS3), U2.35 (RS3), U7.10 (A3); also elsewhere on the board
A4: U7.11 (A4); also elsewhere on the board
A5: U7.12 (A5); also elsewhere on the board
A6: U7.13 (A6); also elsewhere on the board
A7: U7.14 (A7); also elsewhere on the board
A8: U7.15 (A8); also elsewhere on the board
A9: U7.16 (A9); also elsewhere on the board
A10: U7.17 (A10); also elsewhere on the board
A11: U7.18 (A11); also elsewhere on the board
A12: RP4.8, U7.19 (A12); also elsewhere on the board
A13: RP4.6, U7.20 (A13); also elsewhere on the board
A14: RP4.5, U7.22 (A14); also elsewhere on the board
A15: RP4.4, U7.23 (A15); also elsewhere on the board
BTNA\~LP~: CN1.8, CN9.6, U1.14 (PB4); also elsewhere on the board
CAEC: U7.5 (~AEC~); also elsewhere on the board
CAN+5V: C63.1, C64.1, C65.1, C66.1, C102.1, C103.1, L1.1, L2.1, VR2.2; also elsewhere on the board
D0: U1.33 (D0), U2.33 (D0), U7.37 (D0); also elsewhere on the board
D1: U1.32 (D1), U2.32 (D1), U7.36 (D1); also elsewhere on the board
D2: U1.31 (D2), U2.31 (D2), U7.35 (D2); also elsewhere on the board
D3: U1.30 (D3), U2.30 (D3), U7.34 (D3); also elsewhere on the board
D4: U1.29 (D4), U2.29 (D4), U7.33 (D4); also elsewhere on the board
D5: U1.28 (D5), U2.28 (D5), U7.32 (D5); also elsewhere on the board
D6: U1.27 (D6), U2.27 (D6), U7.31 (D6); also elsewhere on the board
D7: U1.26 (D7), U2.26 (D7), U7.30 (D7); also elsewhere on the board
DOT_CLOCK: C36.1, FB17.2; also elsewhere on the board
unnamed: C18.2, CR2.1 (K), Q1.3 (B), Q2.2 (C), R2.2
unnamed: C20.2, CN7.7, L4.2
unnamed: C21.2, C98.1, F1.2, L4.1
unnamed: C23.1, R33.2, U20.1 (DISA), U20.2 (THRA)
unnamed: C24.1, R34.2, U20.12 (THRB), U20.13 (DISB)
unnamed: C61.1, L1.2
unnamed: C70.1, Y1.2
unnamed: C70.2, U31.13
unnamed: C83.1, U30.11 (LOAD), U30.12 (CRY)
unnamed: C85.1, R17.2
unnamed: C85.2, Q7.3 (B), R19.1
unnamed: C86.1, U31.5 (CX2)
unnamed: C86.2, U31.4 (CX1)
unnamed: C87.1, R22.1, R23.2
unnamed: C88.1, C89.1, CR5.1 (K), VR1.1
unnamed: C90.1, CR5.2 (A), CR6.1 (K)
unnamed: C97.2, L5.2, SW1.4
unnamed: C105.2, R50.2, U20.8 (TRIGB)
unnamed: C107.1, R26.2, U31.15
unnamed: C58.1, C108.1, R27.3, U31.1 (FC)
unnamed: CN3.C,3, FB2.1
unnamed: CN7.4, CN7.5, SW1.5
unnamed: CN7.6, SW1.2
unnamed: CR1.1 (K), R5.2, R37.1, U27.12
unnamed: FB2.2, Q3.3 (E)
unnamed: FB16.1, U31.10 (Y), XT1.3 (RFout)
unnamed: FB17.1, U31.7 (Y)
unnamed: FB19.1, L2.2
unnamed: FB21.1, R39.2
unnamed: Q1.1 (E), Q3.1 (B)
unnamed: Q2.3 (B), R3.1, R4.1
unnamed: Q7.1 (E), U32.9
unnamed: R16.2, R17.1, U31.2 (FC), U32.8
unnamed: R19.2, U32.5, U32.10
unnamed: R27.1, R53.2
unnamed: R27.2, R52.1
unnamed: U8.5, U20.5 (OUTA)
unnamed: U8.13, U20.9 (OUTB)
unnamed: U29.5 (Q), U30.9 (D)
unnamed: U29.9 (Q), U32.1
unnamed: U29.8 (~Q~), U29.12 (D)
unnamed: U31.12, Y1.1
unnamed: U32.2, U32.11
unnamed: U32.4, U32.13
PHI0: U7.1 (PH0IN), U32.3; also elsewhere on the board
PHI2: FB5.1, U1.25 (PH2), U2.25 (PH2); also elsewhere on the board
PHI_COLOR: FB16.2, U30.5 (CNT_UP); also elsewhere on the board
POTX: U28.2 (Z0), U28.9 (Z2); also elsewhere on the board
POTY: U28.3 (Z1), U28.10 (Z3); also elsewhere on the board
RDY: U7.2 (RDY); also elsewhere on the board
R\~W~: U1.22 (R/~W~), U2.22 (R/~W~), U7.38 (R/~W~); also elsewhere on the board
~CHAREN~: R43.2, U7.27 (P2); also elsewhere on the board
~CIA1~: U1.23 (~CS~); also elsewhere on the board
~CIA2~: U2.23 (~CS~); also elsewhere on the board
~HIRAM~: R44.2, U7.28 (P1); also elsewhere on the board
~IRQ~: U1.21 (~IRQ~), U7.3 (~IRQ~); also elsewhere on the board
~LORAM~: R45.2, U7.29 (P0); also elsewhere on the board
~NMI~: RP3.3, U2.21 (~IRQ~), U7.4 (~NMI~), U8.6; also elsewhere on the board
~RESET~: CN2.3, CN4.6, R36.2, U1.34 (~RES~), U2.34 (~RES~), U7.40 (~RES~), U8.12; also elsewhere on the board
~VA14~: U2.2 (PA0); also elsewhere on the board
~VA15~: U2.3 (PA1); also elsewhere on the board

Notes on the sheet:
SERIAL BUS
(6-PIN FEMALE DIN)
(24-PIN MALE EDGE)
USER PORT
RP3 3.3K
KEYBOARD
(20-PIN MALE)
(MALE DB9)
CONTROL PORT2
CONTROL PORT1
25V
2.7V
Cut here, and add 1K resistor
Piggyback 0.1uF cap here
RP4 3.3K
7.5V
(6-PIN MALE EDGE)
CASSETTE
LED CONNECTOR
100V
POWER INPUT
(7PIN MALE DIN)
16V
50V
No R101
( 14.31818 MHz - NTSC ) ( 17.734472 MHz - PAL )
To Cartridge Expansion

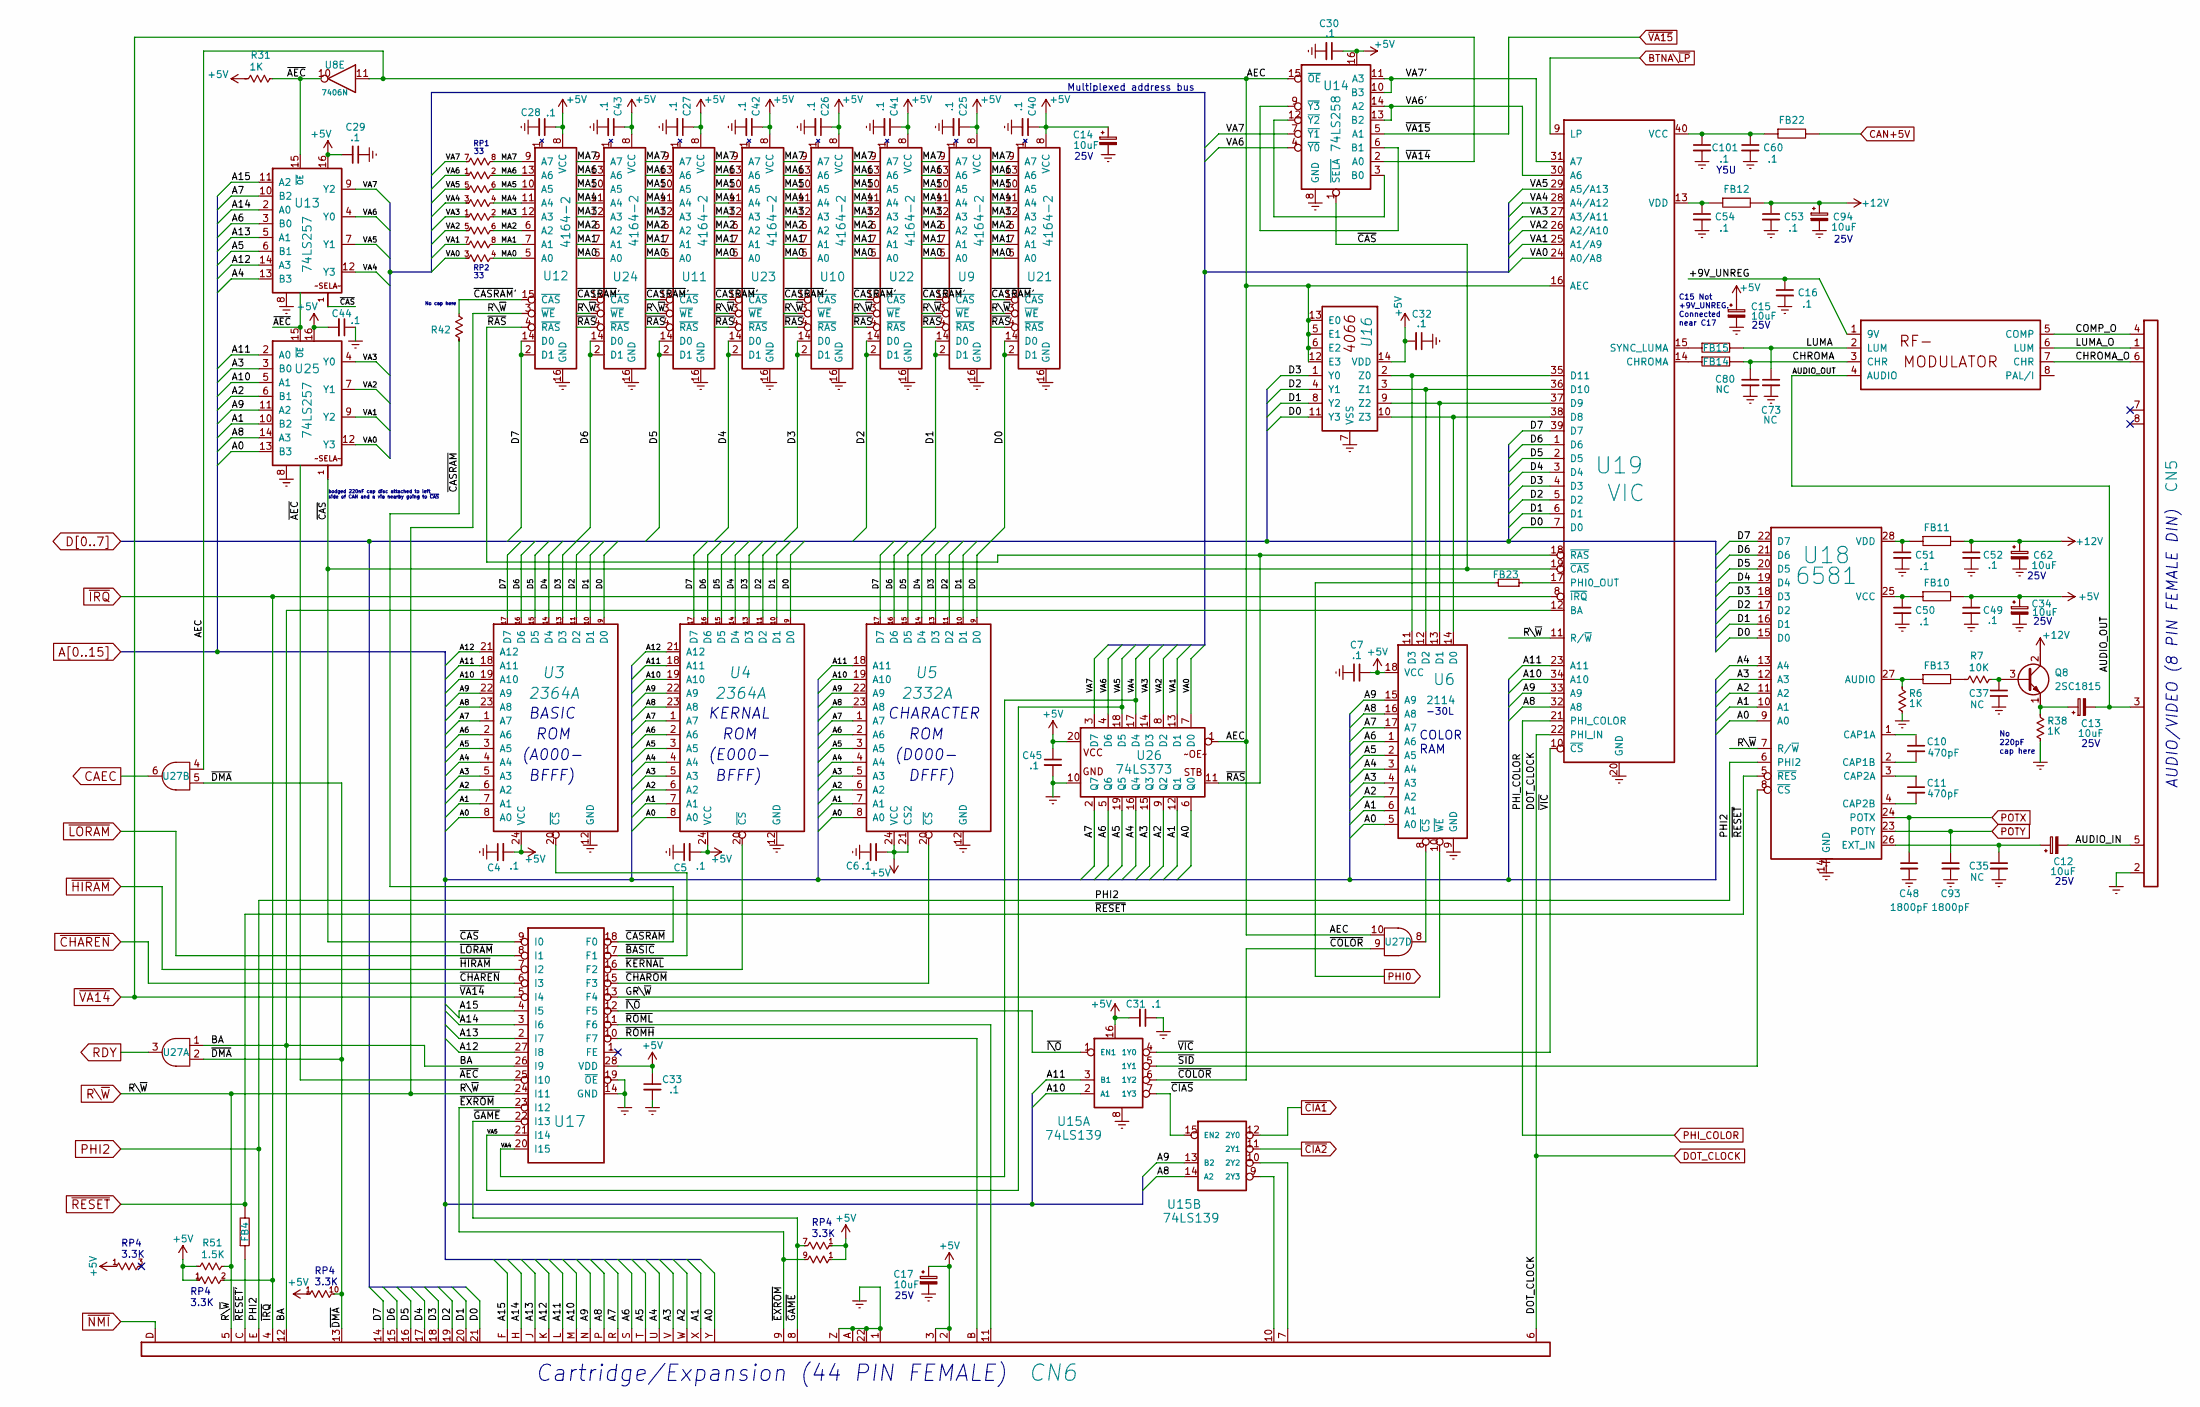
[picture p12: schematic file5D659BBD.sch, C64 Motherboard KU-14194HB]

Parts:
C4, C5, C6, C7, C16, C25, C26, C27, C28, C29, C30, C31, C32, C33, C40, C41, C42, C43, C44, C45, C50, C51, C53, C54, C60, C101: .1; CAP_P5.08mm
C10, C11: 470pF; CAP_AXIAL_P10.16mm
C12, C13, C14, C15, C17, C34, C62, C94: 10uF; CAP_ELYT_RADIAL_P2.54mm
C35, C37: NC; CAP_P5.08mm
C48, C93: 1800pF; RESISTOR_10.16mm
C49, C52: .1; CAP_P12mm
C73, C80: NC; CAP_AXIAL_P12.7mm
CN5: AV_CONN; AV_CON_DIN8
CN6: EXPANSION_PORT
FB4, FB10, FB11, FB12, FB13, FB14, FB15, FB22: FERRITE_BEAD; FERRITE_BEAD_TH_P12.7mm
FB23: FERRITE_NARROW; FERRITE_BEAD_TH_P12.7mm
M1: MODULATOR_LONGBOARD; MODULATOR_PORT_LONGBOARD
Q8: 2SC1815; Q_NPN_ECB
R6, R31, R38: 1K; RESISTOR
R7: 10K; RESISTOR
R42: RESISTOR
R51: 1.5K; RESISTOR
RP1, RP2: 33; RP_ARRAY_7WAY
RP4: R_ARRAY_9WAY_US; RP_ARRAY_9WAY
U3, U4: 2364A; DIP24
U5: 2332A; DIP24
U6: 2114; DIP18
U8: 7406N; DIP14
U9, U10, U11, U12, U21, U22, U23, U24: 4164-2; DIP16
U13, U25: 74LS257; DIP16
U14: 74LS258; DIP16
U15: 74LS139; DIP16
U16: 4066_U28; DIP14
U17: PLA_U17; DIP28
U18: 6581; DIP28
U19: VIC; DIP40
U26: 74LS373; DIP20
U27: 7408_U27; DIP14

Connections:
+5V: C4.2, C5.2, C6.2, C7.1, C14.1, C15.1, C17.1, C25.1, C26.1, C27.1, C28.1, C29.2, C30.1, C31.2, C32.2, C33.1, C34.1, C40.1, C41.1, C42.1, C43.1, C44.2, C45.1, C49.1, CN6.2, CN6.3, FB10.2, R31.2, R51.2, RP4.1, U3.24 (VCC), U4.24 (VCC), U5.21 (CS2), U5.24 (VCC), U6.18 (VCC), U9.8 (VCC), U10.8 (VCC), U11.8 (VCC), U12.8 (VCC), U13.16, U14.16, U15.16, U16.14 (VDD), U17.28 (VDD), U21.8 (VCC), U22.8 (VCC), U23.8 (VCC), U24.8 (VCC), U25.16, U26.20; also elsewhere on the board
+9V_UNREG: C16.1, M1.1 (9V); also elsewhere on the board
+12V: C52.1, C53.1, C62.1, C94.1, FB11.2, FB12.2, Q8.2 (C); also elsewhere on the board
/Sheet5D659BBD/AEC: U8.11, U14.15 (~OE~), U16.5 (E1), U16.6 (E2), U16.12 (E3), U16.13 (E0), U19.16 (AEC), U26.1, U27.4, U27.10
/Sheet5D659BBD/AUDIO_IN: C12.2, CN5.5
/Sheet5D659BBD/AUDIO_OUT: C13.2, CN5.3, M1.4 (AUDIO)
/Sheet5D659BBD/BA: CN6.12, U17.26 (I9), U19.12 (BA), U27.1
/Sheet5D659BBD/CHROMA: C80.1, FB14.2, M1.3 (CHR)
/Sheet5D659BBD/CHROMA_O: CN5.6, M1.7 (CHR)
/Sheet5D659BBD/COMP_O: CN5.4, M1.5 (COMP)
/Sheet5D659BBD/GR\~W~: U6.10 (~WE~), U17.13 (F4)
/Sheet5D659BBD/LUMA: C73.1, FB15.2, M1.2 (LUM)
/Sheet5D659BBD/LUMA_O: CN5.1, M1.6 (LUM)
/Sheet5D659BBD/MA0: RP2.4, U9.5 (A0), U10.5 (A0), U11.5 (A0), U12.5 (A0), U21.5 (A0), U22.5 (A0), U23.5 (A0), U24.5 (A0)
/Sheet5D659BBD/MA1: RP2.8, U9.7 (A1), U10.7 (A1), U11.7 (A1), U12.7 (A1), U21.7 (A1), U22.7 (A1), U23.7 (A1), U24.7 (A1)
/Sheet5D659BBD/MA2: RP2.6, U9.6 (A2), U10.6 (A2), U11.6 (A2), U12.6 (A2), U21.6 (A2), U22.6 (A2), U23.6 (A2), U24.6 (A2)
/Sheet5D659BBD/MA3: RP2.2, U9.12 (A3), U10.12 (A3), U11.12 (A3), U12.12 (A3), U21.12 (A3), U22.12 (A3), U23.12 (A3), U24.12 (A3)
/Sheet5D659BBD/MA4: RP1.4, U9.11 (A4), U10.11 (A4), U11.11 (A4), U12.11 (A4), U21.11 (A4), U22.11 (A4), U23.11 (A4), U24.11 (A4)
/Sheet5D659BBD/MA5: RP1.6, U9.10 (A5), U10.10 (A5), U11.10 (A5), U12.10 (A5), U21.10 (A5), U22.10 (A5), U23.10 (A5), U24.10 (A5)
/Sheet5D659BBD/MA6: RP1.2, U9.13 (A6), U10.13 (A6), U11.13 (A6), U12.13 (A6), U21.13 (A6), U22.13 (A6), U23.13 (A6), U24.13 (A6)
/Sheet5D659BBD/MA7: RP1.8, U9.9 (A7), U10.9 (A7), U11.9 (A7), U12.9 (A7), U21.9 (A7), U22.9 (A7), U23.9 (A7), U24.9 (A7)
/Sheet5D659BBD/VA0: RP2.3, U19.24 (A0/A8), U25.12 (Y3), U26.7 (D0)
/Sheet5D659BBD/VA1: RP2.7, U19.25 (A1/A9), U25.9 (Y2), U26.13 (D1)
/Sheet5D659BBD/VA2: RP2.5, U19.26 (A2/A10), U25.7 (Y1), U26.8 (D2)
/Sheet5D659BBD/VA3: RP2.1, U19.27 (A3/A11), U25.4 (Y0), U26.14 (D3)
/Sheet5D659BBD/VA4: RP1.3, U13.12 (Y3), U17.20 (I15), U19.28 (A4/A12), U26.17 (D4)
/Sheet5D659BBD/VA5: RP1.5, U13.7 (Y1), U17.21 (I14), U19.29 (A5/A13), U26.18 (D5)
/Sheet5D659BBD/VA6: RP1.1, U13.4 (Y0), U14.4 (~Y0~), U26.4 (D6)
/Sheet5D659BBD/VA6': U14.13 (B2), U14.14 (A2), U19.30 (A6)
/Sheet5D659BBD/VA7: RP1.7, U13.9 (Y2), U14.7 (~Y1~), U26.3 (D7)
/Sheet5D659BBD/VA7': U14.10 (B3), U14.11 (A3), U19.31 (A7)
/Sheet5D659BBD/~AEC~: R31.1, U8.10, U13.15 (~OE~), U17.25 (I10), U25.15 (~OE~)
/Sheet5D659BBD/~BASIC~: U3.20 (~CS~), U17.17 (F1)
/Sheet5D659BBD/~CASRAM~: R42.2, U17.18 (F0)
/Sheet5D659BBD/~CASRAM~': R42.1, U9.15 (~CAS~), U10.15 (~CAS~), U11.15 (~CAS~), U12.15 (~CAS~), U21.15 (~CAS~), U22.15 (~CAS~), U23.15 (~CAS~), U24.15 (~CAS~)
/Sheet5D659BBD/~CAS~: U13.1 (~SELA~), U14.1 (~SELA~), U17.9 (I0), U19.19 (~CAS~), U25.1 (~SELA~)
/Sheet5D659BBD/~CHAROM~: U5.20 (~CS~), U17.15 (F3)
/Sheet5D659BBD/~CIAS~: U15.7 (1Y3), U15.15 (EN2)
/Sheet5D659BBD/~COLOR~: U15.6 (1Y2), U27.9
/Sheet5D659BBD/~DMA~: CN6.13, RP4.10, U27.2, U27.5
/Sheet5D659BBD/~EXROM~: CN6.9, RP4.9, U17.23 (I12)
/Sheet5D659BBD/~GAME~: CN6.8, RP4.7, U17.22 (I13)
/Sheet5D659BBD/~I\O~: U15.1 (EN1), U17.12 (F5)
/Sheet5D659BBD/~KERNAL: U4.20 (~CS~), U17.16 (F2)
/Sheet5D659BBD/~RAS~: U9.4 (~RAS~), U10.4 (~RAS~), U11.4 (~RAS~), U12.4 (~RAS~), U19.18 (~RAS~), U21.4 (~RAS~), U22.4 (~RAS~), U23.4 (~RAS~), U24.4 (~RAS~), U26.11
/Sheet5D659BBD/~RESET'~: CN6.C, FB4.1
/Sheet5D659BBD/~ROMH~: CN6.B, U17.10 (F7)
/Sheet5D659BBD/~ROML~: CN6.11, U17.11 (F6)
/Sheet5D659BBD/~SID~: U15.5 (1Y1), U18.8 (~CS~)
/Sheet5D659BBD/~VIC~: U15.4 (1Y0), U19.10 (~CS~)
A0: CN6.Y, U3.8 (A0), U4.8 (A0), U5.8 (A0), U6.5 (A0), U18.9 (A0), U25.13 (B3), U26.6 (Q0); also elsewhere on the board
A1: CN6.X, U3.7 (A1), U4.7 (A1), U5.7 (A1), U6.6 (A1), U18.10 (A1), U25.10 (B2), U26.12 (Q1); also elsewhere on the board
A2: CN6.W, U3.6 (A2), U4.6 (A2), U5.6 (A2), U6.7 (A2), U18.11 (A2), U25.6 (B1), U26.9 (Q2); also elsewhere on the board
A3: CN6.V, U3.5 (A3), U4.5 (A3), U5.5 (A3), U6.4 (A3), U18.12 (A3), U25.3 (B0), U26.15 (Q3); also elsewhere on the board
A4: CN6.U, U3.4 (A4), U4.4 (A4), U5.4 (A4), U6.3 (A4), U13.13 (B3), U18.13 (A4), U26.16 (Q4); also elsewhere on the board
A5: CN6.T, U3.3 (A5), U4.3 (A5), U5.3 (A5), U6.2 (A5), U13.6 (B1), U26.19 (Q5); also elsewhere on the board
A6: CN6.S, U3.2 (A6), U4.2 (A6), U5.2 (A6), U6.1 (A6), U13.3 (B0), U26.5 (Q6); also elsewhere on the board
A7: CN6.R, U3.1 (A7), U4.1 (A7), U5.1 (A7), U6.17 (A7), U13.10 (B2), U26.2 (Q7); also elsewhere on the board
A8: CN6.P, U3.23 (A8), U4.23 (A8), U5.23 (A8), U6.16 (A8), U15.14 (A2), U19.32 (A8), U25.14 (A3); also elsewhere on the board
A9: CN6.N, U3.22 (A9), U4.22 (A9), U5.22 (A9), U6.15 (A9), U15.13 (B2), U19.33 (A9), U25.11 (A2); also elsewhere on the board
A10: CN6.M, U3.19 (A10), U4.19 (A10), U5.19 (A10), U15.2 (A1), U19.34 (A10), U25.5 (A1); also elsewhere on the board
A11: CN6.L, U3.18 (A11), U4.18 (A11), U5.18 (A11), U15.3 (B1), U19.23 (A11), U25.2 (A0); also elsewhere on the board
A12: CN6.K, U3.21 (A12), U4.21 (A12), U13.14 (A3), U17.27 (I8); also elsewhere on the board
A13: CN6.J, U13.5 (A1), U17.2 (I7); also elsewhere on the board
A14: CN6.H, U13.2 (A0), U17.3 (I6); also elsewhere on the board
A15: CN6.F, U13.11 (A2), U17.4 (I5); also elsewhere on the board
BTNA\~LP~: U19.9 (LP); also elsewhere on the board
CAEC: U27.6; also elsewhere on the board
CAN+5V: FB22.2; also elsewhere on the board
D0: CN6.21, U3.9 (D0), U4.9 (D0), U5.9 (D0), U16.11 (Y3), U18.15 (D0), U19.7 (D0), U21.2 (D1), U21.14 (D0); also elsewhere on the board
D1: CN6.20, U3.10 (D1), U4.10 (D1), U5.10 (D1), U9.2 (D1), U9.14 (D0), U16.8 (Y2), U18.16 (D1), U19.6 (D1); also elsewhere on the board
D2: CN6.19, U3.11 (D2), U4.11 (D2), U5.11 (D2), U16.4 (Y1), U18.17 (D2), U19.5 (D2), U22.2 (D1), U22.14 (D0); also elsewhere on the board
D3: CN6.18, U3.13 (D3), U4.13 (D3), U5.13 (D3), U10.2 (D1), U10.14 (D0), U16.1 (Y0), U18.18 (D3), U19.4 (D3); also elsewhere on the board
D4: CN6.17, U3.14 (D4), U4.14 (D4), U5.14 (D4), U18.19 (D4), U19.3 (D4), U23.2 (D1), U23.14 (D0); also elsewhere on the board
D5: CN6.16, U3.15 (D5), U4.15 (D5), U5.15 (D5), U11.2 (D1), U11.14 (D0), U18.20 (D5), U19.2 (D5); also elsewhere on the board
D6: CN6.15, U3.16 (D6), U4.16 (D6), U5.16 (D6), U18.21 (D6), U19.1 (D6), U24.2 (D1), U24.14 (D0); also elsewhere on the board
D7: CN6.14, U3.17 (D7), U4.17 (D7), U5.17 (D7), U12.2 (D1), U12.14 (D0), U18.22 (D7), U19.39 (D7); also elsewhere on the board
DOT_CLOCK: CN6.6, U19.22 (PHI_IN); also elsewhere on the board
unnamed: C10.1, U18.1 (CAP1A)
unnamed: C10.2, U18.2 (CAP1B)
unnamed: C11.1, U18.3 (CAP2A)
unnamed: C11.2, U18.4 (CAP2B)
unnamed: C12.1, C35.1, U18.26 (EXT_IN)
unnamed: C13.1, Q8.1 (E), R38.2
unnamed: C37.1, Q8.3 (B), R7.1
unnamed: C50.1, FB10.1, U18.25 (VCC)
unnamed: C51.1, FB11.1, U18.28 (VDD)
unnamed: C54.1, FB12.1, U19.13 (VDD)
unnamed: C60.1, C101.1, FB22.1, U19.40 (VCC)
unnamed: CN6.7, U15.10 (2Y2)
unnamed: CN6.10, U15.9 (2Y3)
unnamed: FB13.1, R6.2, U18.27 (AUDIO)
unnamed: FB13.2, R7.2
unnamed: FB14.1, U19.14 (CHROMA)
unnamed: FB15.1, U19.15 (SYNC_LUMA)
unnamed: FB23.1, U19.17 (PHI0_OUT)
unnamed: U14.6 (B1), U14.9 (~Y3~)
unnamed: U14.3 (B0), U14.12 (~Y2~)
unnamed: U6.11 (D3), U16.2 (Z0), U19.35 (D11)
unnamed: U6.12 (D2), U16.3 (Z1), U19.36 (D10)
unnamed: U6.13 (D1), U16.9 (Z2), U19.37 (D9)
unnamed: U6.14 (D0), U16.10 (Z3), U19.38 (D8)
unnamed: U6.8 (~CS~), U27.8
PHI0: FB23.2; also elsewhere on the board
PHI2: CN6.E, U18.6 (PHI2); also elsewhere on the board
PHI_COLOR: U19.21 (PHI_COLOR); also elsewhere on the board
POTX: C48.1, U18.24 (POTX); also elsewhere on the board
POTY: C93.1, U18.23 (POTY); also elsewhere on the board
RDY: U27.3; also elsewhere on the board
R\~W~: CN6.5, R51.1, U9.3 (~WE~), U10.3 (~WE~), U11.3 (~WE~), U12.3 (~WE~), U17.24 (I11), U18.7 (R/~W~), U19.11 (R/~W~), U21.3 (~WE~), U22.3 (~WE~), U23.3 (~WE~), U24.3 (~WE~); also elsewhere on the board
~CHAREN~: U17.6 (I3); also elsewhere on the board
~CIA1~: U15.12 (2Y0); also elsewhere on the board
~CIA2~: U15.11 (2Y1); also elsewhere on the board
~HIRAM~: U17.7 (I2); also elsewhere on the board
~IRQ~: CN6.4, RP4.2, U19.8 (~IRQ~); also elsewhere on the board
~LORAM~: U17.8 (I1); also elsewhere on the board
~NMI~: CN6.D; also elsewhere on the board
~RESET~: FB4.2, U18.5 (~RES~); also elsewhere on the board
~VA14~: U14.2 (A0), U17.5 (I4); also elsewhere on the board
~VA15~: U14.5 (A1); also elsewhere on the board

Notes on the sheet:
RP1
RP2
bodged 220nF cap disc attached to left side of CAN and a via nearby going to ~CAS~
No cap here
BASIC
ROM
(A000-
BFFF)
KERNAL
(E000-
CHARACTER
(D000-
DFFF)
RP4 3.3K
Cartridge/Expansion (44 PIN FEMALE)
Multiplexed address bus
25V
-30L
COLOR RAM
AUDIO/VIDEO (8 PIN FEMALE DIN)
No 220pF cap here
C15 Not +9V_UNREG. Connected near C17
Y5U

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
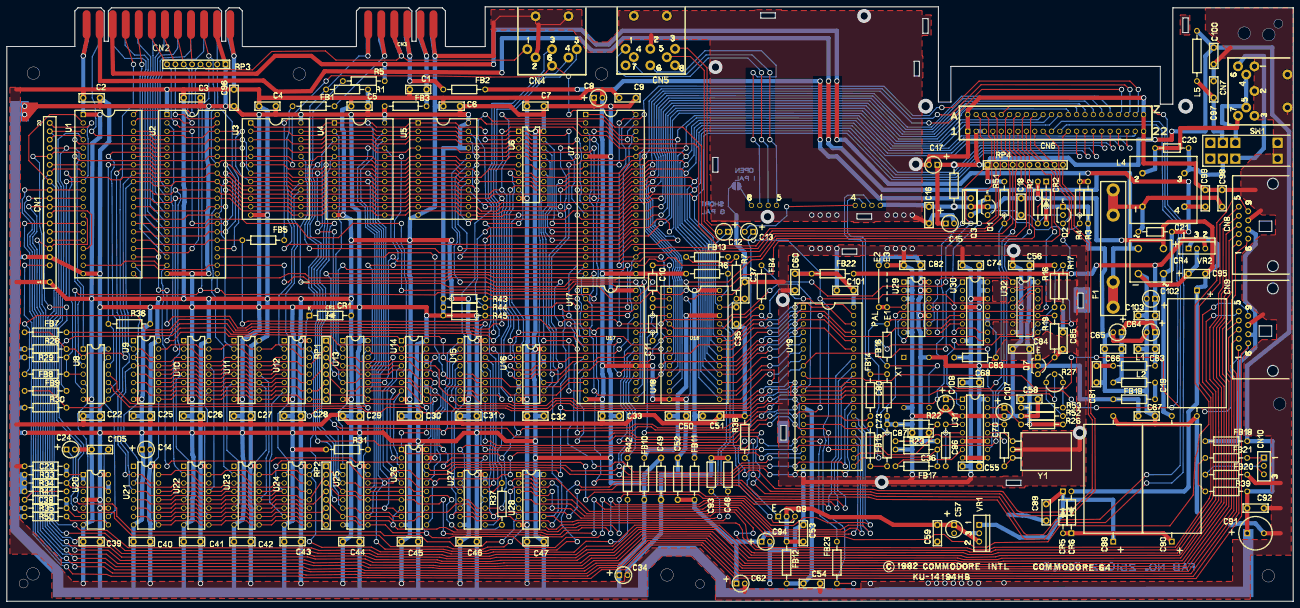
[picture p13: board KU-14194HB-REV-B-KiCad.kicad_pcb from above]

Board: 2 copper layers, 390.2 x 180.3 mm, 221 parts (0 on the bottom side), 227 nets.

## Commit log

2019-08-27 schematics update
    [KU-14194HB-REV-B-KiCad.kicad_pcb, KU-14194HB-REV-B-KiCad.sch, file5D659BBD.sch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]
2019-09-02 more connectors and stuff
    [KU-14194HB-REV-B-KiCad.kicad_pcb, file5D659BBD.sch, file5D940AF3.sch]
2019-09-03 added missing parts. powre connector is upside down in the ku board
    [KU-14194HB-REV-B-KiCad.kicad_pcb, file5D940AF3.sch]
2019-09-08 Oscillator area
    [KU-14194HB-REV-B-KiCad.kicad_pcb, file5D940AF3.sch]
2019-09-19 More schematics
    [KU-14194HB-REV-B-KiCad.kicad_pcb, KU-14194HB-REV-B-KiCad.sch, file5D659BBD.sch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]
2019-09-26 Tighter ram symbols. Getting closer to the end of the schematics.
    [KU-14194HB-REV-B-KiCad.kicad_pcb, file5D659BBD.sch, file5D940AF3.sch]
2019-09-28 Almost done now
    [KU-14194HB-REV-B-KiCad.kicad_pcb, file5D659BBD.sch, file5D940AF3.sch]
2019-09-28 Schematics PDF and screenshot update
    [KU-14194HB-REV-B-KiCad.sch, file5D659BBD.sch, file5D940AF3.sch]
2019-09-29 AV connector, Not used parts, pdf update
    [KU-14194HB-REV-B-KiCad.kicad_pcb, KU-14194HB-REV-B-KiCad.sch, file5D659BBD.sch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]
2019-09-30 Polygons to fill zones. Reducing DRC errors.
    [KU-14194HB-REV-B-KiCad.kicad_pcb]
2019-10-05 Replica 1.0
    [KU-14194HB-REV-B-KiCad-B_Cu.gbr, KU-14194HB-REV-B-KiCad-B_Mask.gbr, KU-14194HB-REV-B-KiCad-B_Paste.gbr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]
2019-10-15 V1.1 Layout: Fixed missing keying-slot in user port.
    [KU-14194HB-REV-B-KiCad-B_Cu.gbr, KU-14194HB-REV-B-KiCad-B_Mask.gbr, KU-14194HB-REV-B-KiCad-B_Paste.gbr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]
2019-10-15 update soldermask with V1.1
    [KU-14194HB-REV-B-KiCad-B_Cu.gbr, KU-14194HB-REV-B-KiCad-B_Mask.gbr, KU-14194HB-REV-B-KiCad-B_Paste.gbr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]
2019-11-10 Rev 1.2
    Added missing C14
    [KU-14194HB-REV-B-KiCad-B_Cu.gbr, KU-14194HB-REV-B-KiCad-B_Mask.gbr, KU-14194HB-REV-B-KiCad-B_Paste.gbr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]
2019-11-12 Update V1.3
    See readme
    [KU-14194HB-REV-B-KiCad-B_Cu.gbr, KU-14194HB-REV-B-KiCad-B_Mask.gbr, KU-14194HB-REV-B-KiCad-B_Paste.gbr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]
2019-11-12 V1.3 C70
    [file5D940AF3.sch]
2019-11-18 value updates
    [file5D659BBD.sch, file5D940AF3.sch]
2020-01-04 adding a bom for replica 1.3
    [bom_v1.3.csv]
2020-01-22 Rev 1.4. See Readme
    [KU-14194HB-REV-B-KiCad-B_Cu.gbr, KU-14194HB-REV-B-KiCad-B_Mask.gbr, KU-14194HB-REV-B-KiCad-B_Paste.gbr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]
2020-09-12 removed solder paste from edge connectors. moved the solder mask openings from the board to the edge connectors themselves.
    [KU-14194HB-REV-B-KiCad.kicad_pcb, unitary_ring.fcstd]
2020-09-12 Added outline drawings (Dwgs.User layer) on the edge connectors for those who want to reuse these footprints in another design, the can use these lines as guide for the edge.cut layer (kicad does not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
    [KU-14194HB-REV-B-KiCad.kicad_pcb]
2020-12-29 interactive-bom generated using plugin
2021-01-10 moved silkscreen from board to footprint library
    [KU-14194HB-REV-B-KiCad.kicad_pcb, KU-14194HB-REV-B-KiCad.sch, file5D659BBD.sch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]
2021-03-10 moved silkscreen into some commodore-part footprints
    [KU-14194HB-REV-B-KiCad.kicad_pcb]
2021-03-14 Moving silscreen art from board to footprints
    [KU-14194HB-REV-B-KiCad.kicad_pcb]
2021-04-01 Update README.md with the Interactive-BOM preview.
2021-04-10 Updated README.md. Added link to forum64.de thread "Bilder Showroom"
2021-07-26 added *rescue.lib to the repo, including some small changes to the bom #5
    [bom.csv, file5D940AF3.sch]
